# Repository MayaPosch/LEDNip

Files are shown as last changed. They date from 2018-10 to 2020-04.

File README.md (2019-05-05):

# LED'Nip #

 LED'Nip is a 5-channel Cortex-M4-based LED controller and general STM32 development board. It has the following features:

- STM32F427 microcontroller (Cortex-M4, 180 MHz).
- 100 MBit Ethernet (LAN8472A).
- CAN (RJ-45 jacks).
- Three 12V channels for RGB LED strips or similar.
- Two channels for ~25 Watt LED panels each (5.5/2.1 mm jack) with constant current regulator (1A LDD-1000H or equivalent per channel).
- 24 VDC board supply voltage.
- SPI, I2C, U(S)ART, I2S and JTAG broken out into JST PH headers.

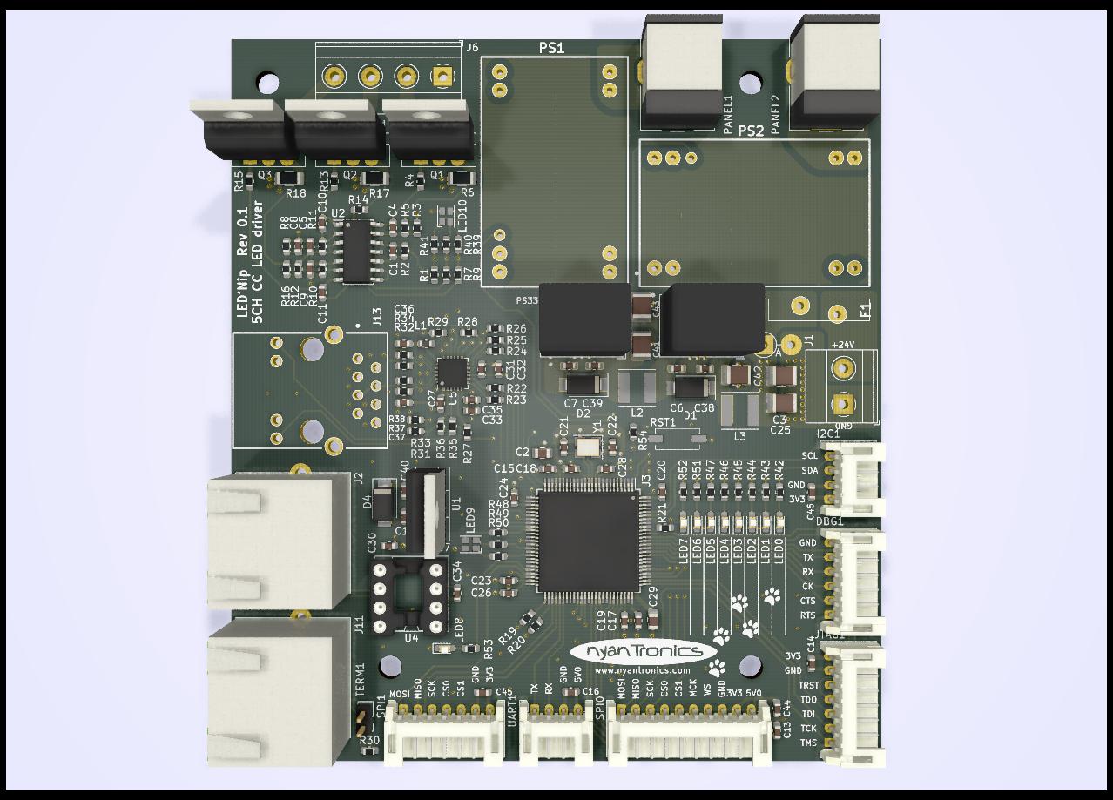
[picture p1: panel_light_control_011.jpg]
LED'Nip


## Status ##

The LED'Nip hardware has been mostly validated. Test firmware can be found in its folder, with the firmware and backend service that will allow for the board to be used with building lighting and similar still under development.

## Project page

A project & product page can be found at: [http://www.nyantronics.com/lednip.php](http://www.nyantronics.com/lednip.php "LED'Nip")

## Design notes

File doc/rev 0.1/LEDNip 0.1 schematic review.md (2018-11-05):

LEDNip 0.1 schematic review
===

OSHW Logo and license:
https://maciek134.github.io/oshw-logo-gen/

5 channel LED driver board with 10/100 ethernet and CAN BUS control. 

**Modules**
R78B12-2.0, R78B33-2.0 https://www.recom-power.com/pdf/Innoline/R-78Bxx-2.0.pdf
LDD-1000H https://www.mouser.com/ds/2/260/LDD-H-spec-766227.pdf
**ICs**
LM324 http://www.ti.com/lit/ds/snosc16d/snosc16d.pdf
STM32F207VGT6 https://www.st.com/resource/en/datasheet/stm32f207zg.pdf
MCP2562 http://hades.mech.northwestern.edu/images/5/5e/MCP2562.pdf
LAN8720A http://ww1.microchip.com/downloads/en/devicedoc/8720a.pdf
**Connectors**
HR911105A http://www.kosmodrom.com.ua/pdf/HR911105A.pdf
JST PH http://www.farnell.com/datasheets/1699381.pdf
CUI PJ-063AH https://www.cui.com/product/resource/pj-063ah.pdf
RJHSE-5380A1 https://www.mouser.de/datasheet/2/18/rjhsel38x02-1395709.pdf
Metz 31349102, 31349104 (Reichelt AKL349-xx) https://www.metz-connect.com/us/system/files/productfiles/Data_sheet_313491_RP015xxVBLC_OFF-023252M.pdf
Metz 31330102, 31330104 (Reichelt AKL330-xx) https://www.metz-connect.com/en/system/files/productfiles/Data_sheet_313301_PT115xxHBBN_OFF-022949N.pdf

Quick Review:
===

Schematic ERC
---
- nets with power inputs and no power outputs (even connectors) need a PWR_FLAG to represent power output, passives disconnect power nets (need another PWR_FLAG after filter inductor / resistor)
- no multiple bidirectional pins on one net (multiple output short prohibited)
- no bidirectional pin connected to a net with power output or PWR_FLAG (including ground)
- GND also needs one PWR_FLAG in the entire circuit
- more rules.. go figure

RMII interface signals
----
http://ebook.pldworld.com/_eBook/-Telecommunications,Networks-/TCPIP/RMII/rmii_rev12.pdf
https://en.wikipedia.org/wiki/Media-independent_interface
|Signal name |	Description |	Direction |
|---|---|---|---|
|REF_CLK| Continuous 50 MHz reference clock |	Reference clock may be an input on both devices from an external clock source, or may be driven from the MAC to the PHY |
|TXD0 	| Transmit data bit 0 (transmitted first) |	MAC to PHY |
|TXD1 	| Transmit data bit 1  |	MAC to PHY |
|TX_EN 	| When high, clock data on TXD0 and TXD1 to the transmitter |	MAC to PHY |
|RXD0 	| Receive data bit 0 (received first) |	PHY to MAC |
|RXD1 	| Receive data bit 1 |	PHY to MAC |
|CRS_DV | 	Carrier Sense (CRS) and RX_Data Valid (RX_DV) multiplexed on alternate clock cycles. In 10 Mbit/s mode, it alternates every 10 clock cycles. |	PHY to MAC |
|RX_ER 	| Receive error (optional on switches) |	PHY to MAC |
|MDIO 	| Management data |	Bidirectional |
|MDC 	| Management data clock. |	MAC to PHY |

Microcontroller
---------------
- BOOT strap config
-- https://www.st.com/resource/en/datasheet/stm32f207vg.pdf
-- https://www.st.com/resource/en/schematic_pack/nucleo_144pins_sch.zip
-- RM0033 reference manual: https://www.st.com/content/ccc/resource/technical/document/reference_manual/51/f7/f3/06/cd/b6/46/ec/CD00225773.pdf/files/CD00225773.pdf/jcr:content/translations/en.C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 boot0: Main Flash memory; BOOT0 is a dedicated pin while BOOT1 is ... GPIO; 47k unmotivated -> 1k 
- JTAG / SWD: JTRST->PB4 RM0033 ok (Table 15. Flexible SWJ-DP pin assignment) (Table 207. SWJ debug port pins)
-- JTAG and SWD pinouts verified 
- general pin mapping
-- CubeMX tool: https://www.st.com/en/development-tools/stm32cubemx.html#sw-tools-scroll

- CAN interface
-- "The two CANs are compliant with the 2.0A and B (active) specifications with a bitrate up to 1 Mbit/s. They can receive and transmit standard frames with 11-bit identifiers as well as extended frames with 29-bit identifiers. Each CAN has three transmit mailboxes, two receive FIFOS with 3 stages and 28 shared scalable filter banks"
-- CAN transceiver are equal? CubeMX says: "Master" for CAN1 (RM0033 p.793 "Controller area network (bxCAN)")
-- https://www.st.com/content/ccc/resource/training/technical/product_training/de/ee/37/c6/60/9c/45/a5/STM32L4_Peripheral_CAN.pdf/files/STM32L4_Peripheral_CAN.pdf/jcr:c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 
-- CAN2 RX and TX: changed SPI CS0, CS1 from PB6,PB7 to PB5+PB6 (also maps to the slave BxCAN pins for backup)

- clock generation and distribution
-- XTAL up to 26 MHz (also validated with CubeMX) (https://www.st.com/content/ccc/resource/technical/document/application_note/c6/eb/5e/11/e3/69/43/eb/CD00221665.pdf/files/CD00221665.pdf/jcr:content/translations/en.C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)
-- STM32 and LAN8720A timing requirements (jitter / tolerance), PLL behaviour: (RM0033: "The software has to set these bits correctly to ensure that the VCO input frequency ranges from 1 to 2 MHz. It is recommended to select a frequency of 2 MHz to limit PLL jitter") - 25 MHz could be routed directly from the oscillator (???) -- look at clock distribution: CubeMX: MCO1 supports HSE and PLL 
-- Table 34. Main PLL characteristics (continued): Cycle-to-cycle jitter 25ps RMS, +/-150ps(peak-peak), Period Jitter: 15ps, +/-200ps (peak-peak)
-- LAN8720A: CLKIN  Jitter 150 psec (peak-peak) max, 
- RMII timing analysis
-- datasheet "Table 64. Dynamics characteristics: Ethernet MAC signals for RMII" have to be met. All RMII traces are 50 mm max., accounting for < 300ps propagation delays. LAN8720A "Table 5.9 RMII Timing Values (REF_CLK Out Mode)" has the timing characteristics in REFCLKO mode.
-- at first glance, the mismatch between RXDn and REFCLK lines from PHY to MAC is < 10 mm, so the RX path signals can be considered to have perfect timing. For the TX path this already introduces a delay by how long it takes REFCLKO to propagate ~30 mm. The period of REFCLK is 20 ns and the MAC provides 9 ns minimum TXD and TXEN hold, followed by a transition zone of about 5 ns until the next transmit data is stable so there is a 20 ns- (9 + 5 ) ns = 6 ns minimum setup earlier on. When looked at from the MAC, the PHY clock is slightly ahead in time and along with it the PHY sampling edges. Consequently the PHY sampling is advanced by the PHY-> MAC REFCLK propagation delay plus the MAC->PHY TXDn propagation time. Due to the odd STM32 RMII pin mapping the TXDn traces are 60 mm long. Adding to that the REFCLK trace length we're talking about 100 mm or 0.5 ns propagation delay , leaving 5.5 ns timing buffer for delays and transitions. 
-- conclusion: RMII timing ought to be valid.

- RMII_RXER sowie can_stdby nicht in den alternate Functions, vermutlich da sie softwaremäßig umgesetzt sind
-- CAN_STDBY: GPIO (optional power-down for CAN level converter)
-- ds p.123 "Figure 50. Ethernet RMII timing diagram" RMII requires REF_CLK, RXD[1:0], TXD[1:0], CRS_DV, TX_EN. Table 64 below lists the timing constraints. 
-- RXER is not used on the MAC and connected to a PD on the STM32 nucleo board where the LAN8742A is used (see https://www.st.com/content/ccc/resource/technical/layouts_and_diagrams/schematic_pack/63/95/5c/0c/d6/af/4b/e2/nucleo_144pins_sch.zip/files/nucleo_144pins_sch.zip/jcr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 MB1137.pdf). On our board, it's connected to the microcontroller. As per LAN8720A, RXER acts as start-up PHYAD0 input with internal PD. No further action is required.

- Powersupply erwartet 100nF an jedem Supply-Pin, 7 Supply-Pins, aber nur 5 Caps: 2 vergessen?
-- pins 19, 21, 22 share C2+C15 (100n + 4.7µF). The same applies to C17 + C29

- 3 pF am Quarz ungewohnt wenig, aber Quarztyp im Schematic nicht zu lesen
-- ABM8W-25.0000MHZ-4-D1X-T3 https://www.mouser.de/datasheet/2/3/ABM8W-1107617.pdf und https://abracon.com/uploads/resources/qtzcry_glossary.pdf : C_L = C1*C2/(C1+C2)+C_stray
-- Oscillator design guide for STM8AF/AL/S and STM32 microcontrollers: https://www.st.com/content/ccc/resource/technical/document/application_note/c6/eb/5e/11/e3/69/43/eb/CD00221665.pdf/files/CD00221665.pdf/jcr:content/translations/en.C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 p.26 "Table 6. HSE oscillators embedded in STM32 microcontrollers": Step 1: Check the resonator compatibility with the selected STM32 (gain margin satisfied?), Step 2: Determine the capacitance value of the load capacitors C_L1 and C_L2
-- Datenblattwerte für Quarz C_L: 4pF, oscillator pins ~5pF (datasheet?), C_stray < 0.5 pF? -> ~4pF
-- ggf. sind Varianten mit höherer C_L wünschenswert, siehe AN2867 p.39 "[larger values, lower "pullability"]  can be used in noisy environments, but will impact the power consumption." -> ABM8-25.000MHZ-10-D1G-T (Mouser 815-8W25-4D1XT) -> 15pF load caps: C_L = 10pF
-- can always go crazier, see https://www.st.com/content/ccc/resource/technical/document/application_note/c6/eb/5e/11/e3/69/43/eb/CD00221665.pdf/files/CD00221665.pdf/jcr:content/translations/en.C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 p.33 and below

MCP2562
-------
- Pinout geprüft, keine Fehler
- Beschaltung wie im DS vorgeschlagen

LAN8720A
--------

| Pin | internal | external/override | Selected Function |
|---|---| ---|---|
| RXD0/MODE0 | PU | TRIS | MODE=111: all capable |
| RXD1/MODE1 | PU | TRIS | MODE=111: all capable |
| RXER/PHYAD0  | PD | TRIS | lo : addr = 000 | 
| CRS_DV/MODE2 | PU | TRIS | MODE=111: all capable |
| nINT | PU | TRIS | will be REFCLKO, don't care |
| RST | PU | PU | redundancy, don't care |
| LED1/REGOFF  | PD | LED to GND | lo: regulator active |
| LED2/nINTSEL | PU | PD | lo: REFCLK OUT selected |

validated.

- Pinout geprüft, keine Fehler
- PU/PD config: see above 
- Supply-Beschaltung wie im DS vorgeschlagen
- Warum sind RX-Pins mit 100 Ohm beschaltet, TX aber nicht?
-- series termination resistors are placed near the drivers. TX terminators are associated with the µC.
- Warum hat MDIO einen Pullup, die anderen Pins aber nicht?
-- MDC is driven by the MAC (master, push-pull), whereas MDIO is open drain and can be driven by PHYs and MAC. (Wiki. The MDIO requires a specific pull-up resistor of 1.5 kΩ to 10 kΩ, taking into account the total worst-case leakage current of 32 PHYs and one MAC.)
- An sonsten Beschaltung gemäß DS
-- \o/

HR911105A
---------
- Pinout geprüft, alles ok

LDD-1000H
---------
- Pinout geprüft, alles ok

R-78B3.3-1.0
------------
- Pinout ok
- Eingangsbeschaltung etwas random. Vermutlich einfach BOM kurz halten durch wiederholen von Captypen.
-- LDD-H modules don't necessarily need input bypass caps, leaving just R78B12-2.0. LC pi input filter inspired by the corresponding datasheet.
- D2 fragwürdig.
-- LDO downward compatibility

LED-Ausgangsstufen
------------------
- Pinout OP passt
- Sehe 2 Tiefpass-Filter, einen am Eingang für ca. ~500 Hz, einen aktiven am OP für ca. 50 kHz (BW limiting vs. 3 MHz GBP)

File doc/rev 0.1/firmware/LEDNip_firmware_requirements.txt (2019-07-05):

LEDNip firmware requirements

2019/07/02, Maya Posch
---

> Overview

This document describes the software requirements for the Nyantronics LEDNip board. The requisite backend service is covered in a different document.

---

> Inputs/Outputs

The firmware takes input from:

* Ethernet interface.
* CAN interface.

It has the following outputs:

* 2x PWM pins to control 2 CC LED drivers.
* 3x PWM pins to control 3 LED strip (colour) drivers.

---

> Basic functionality set

These are the minimal features which the firmware has to support for an MVP.

* Obtain an IP address from the DHCP server on the Ethernet network.
* Connect to an MQTT broker on this interface.
* Accept commands on the Ethernet interface via MQTT to:
	* change the outputs to a specific PWM value, ranging from 0 - 100%.
	* return the current values the PWM pins have been set to.

> Details:

Implemented as bare metal, using a basic processing loop.

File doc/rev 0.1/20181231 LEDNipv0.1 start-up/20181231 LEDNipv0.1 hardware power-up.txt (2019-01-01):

LEDNip-0.1 commissioning

Step 1:
3.3V and 0.02A limit to JTAG1 GND|3.3V pins: 3.3V 0.018A -> pass, no shorts
swap PSU: 3.3V (no precision current measurement)

Step 2:
12V rail: 2.4V backdriven through freewheeling diode (as expected)
slowly increase 12V rail to 5V with 0.02A limit, monitoring 3.3V rail
* current limit not exceeded
* 3.3V increases from 3.284V to 3.289V (in spec)
* 12V rail at 4.75V (current limit)
* 5V rail at 3.9V

increase current limit to 0.05A
* 12V rail at 5.0V
* monitor 5V rail, ramd up 12V rail to 12V
* 5V rail settles in at 5.078V (in spec)
* 3.3V rail at 3.308V (in spec)
* 24V rail at 11.48V

remove 3.3V injection
* rails still in spec
turn off power supplies

Step 3:
hook up adjustable power supply to 24V rail

* 24V rail to 3V: no current draw
* 24V rail to 12V: 2-3mA, 3.3V rail at 0.1V
* 24V rail to 14V: overcome UVLO, 16mA current draw
* 12V rail at 12.03V, 5V rail at 5.08V, 3.3V at 3.308V
* 24V rail to 24V: input current now 9mA
* 24V rail at 28V: 8mA

power-up test passed.

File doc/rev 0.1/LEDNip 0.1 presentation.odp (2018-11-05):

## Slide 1

LEDNip 0.1 - 5 channel LED driver board

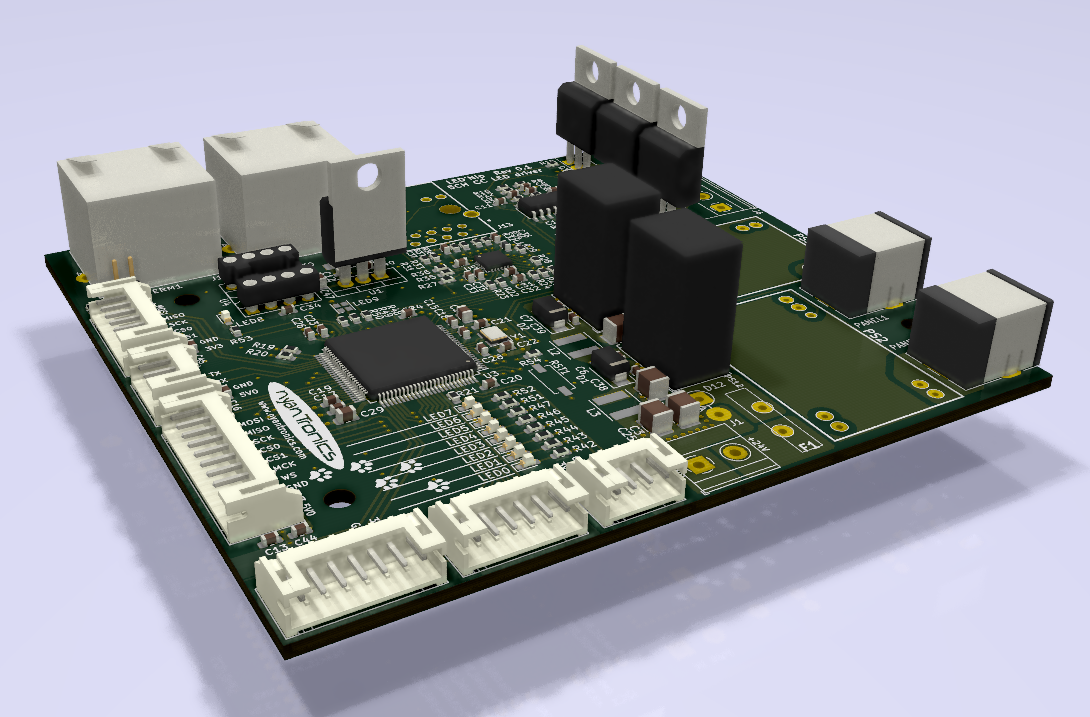
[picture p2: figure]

2018-11-05

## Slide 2

What?

- driver board for indoor LED lighting
- 2-channel 1A CC drivers for 8-24V LED chains (CUI barrel jacks for panels)
- 3-channel 1A CC drivers for RGB strips (linear / PWM)
- control via UART, CAN, Ethernet
- lots of peripherals for extensions and building automation
- compact 9x10cm 4-layer PCB for best performance

Open source hardware project

- multiple maintainers
- KiCAD project files
- open source firmware

BOM cost: 45-55€

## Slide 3

Features:

STM32F427 Cortex-M4 microcontroller

24V input for use with common power supplies (cost-effective fan-less MeanWell 100W)

2x 0..1000 mA CC LED driver

up to 97% efficiency

industry-proven potted module 2000Khrs min. MIL-HDBK-217F

PWM dimming (spec: < 1kHz, tested up to 7 kHz)

12V / 3.3V buck converter modules

multi-sourced potted modules from reputable manufacturers (RECOM, Gap-Tec)

on-board 3-channel current controller for RGB strips

10/100 Ethernet

CAN bus + daisychaining JR45 (CAT5)

JTAG/SWD

lots of interfaces for whatever comes our way

2x UART/USART w/ flow control

2x SPI (option for I2S)

I2C

secondary CAN

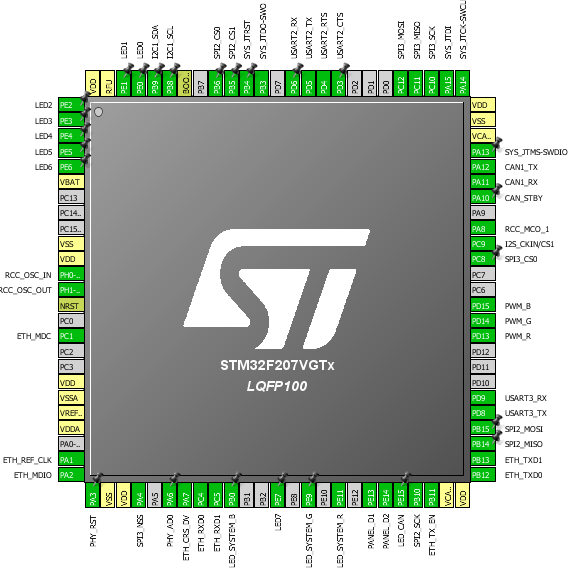
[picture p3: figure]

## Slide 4

multiple controller options:

can be adjusted to applications

less problems sourcing

Design tool CubeMX

Cortex-M3 / Cortex-M4 options

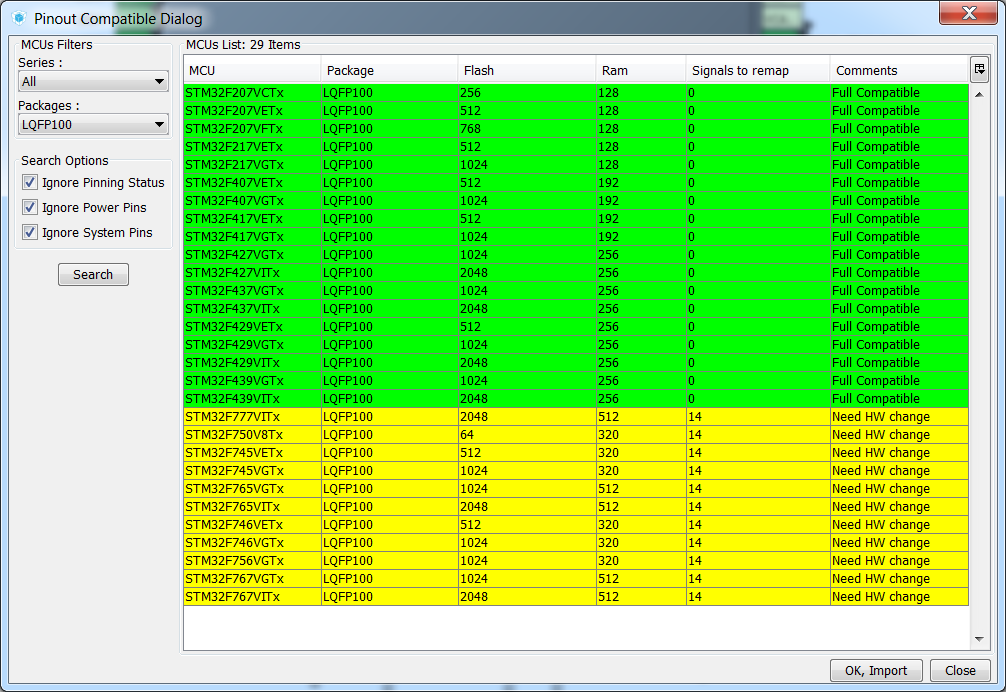
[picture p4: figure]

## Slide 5

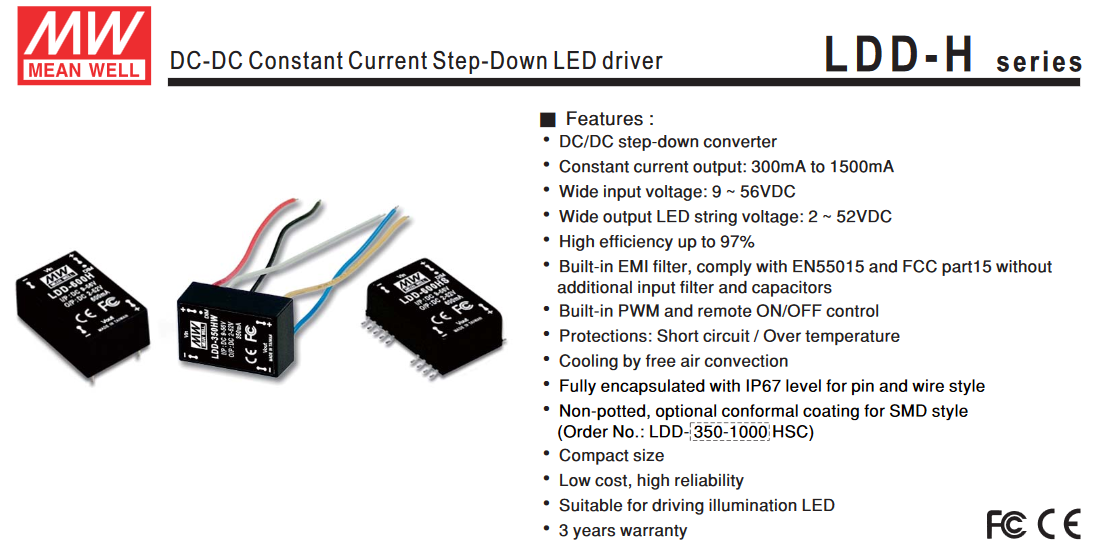
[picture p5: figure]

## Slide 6

Status?

- [done] Schematic design (~30h)
- [done] Schematic review (2 reviewers) (~5h)
- [done] Layout (~70h)
- [done] Layout validation (3 reviewers) (~5h)
- [done] parts availablilty check – mostly sourced from Mouser
- [ongoing] parts attributes in KiCAD and BOM export
- [done] experimental validation MeanWell LDD-1000H
- [done] experimental validation 1A linear CC sinks
- [pending] prototyping strategy (5+25 boards vs. 30+ boards at once, w/ stencil)
- [pending] parts sourcing (mission critical parts stocked)
- [ongoing] PCB assembly capabilities (professional P&P + reflow options, manual)
- [pending] prototype evaluation w/ PCBs
- [ongoing] firmware development

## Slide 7

KiCAD schematics and board files as OSHW

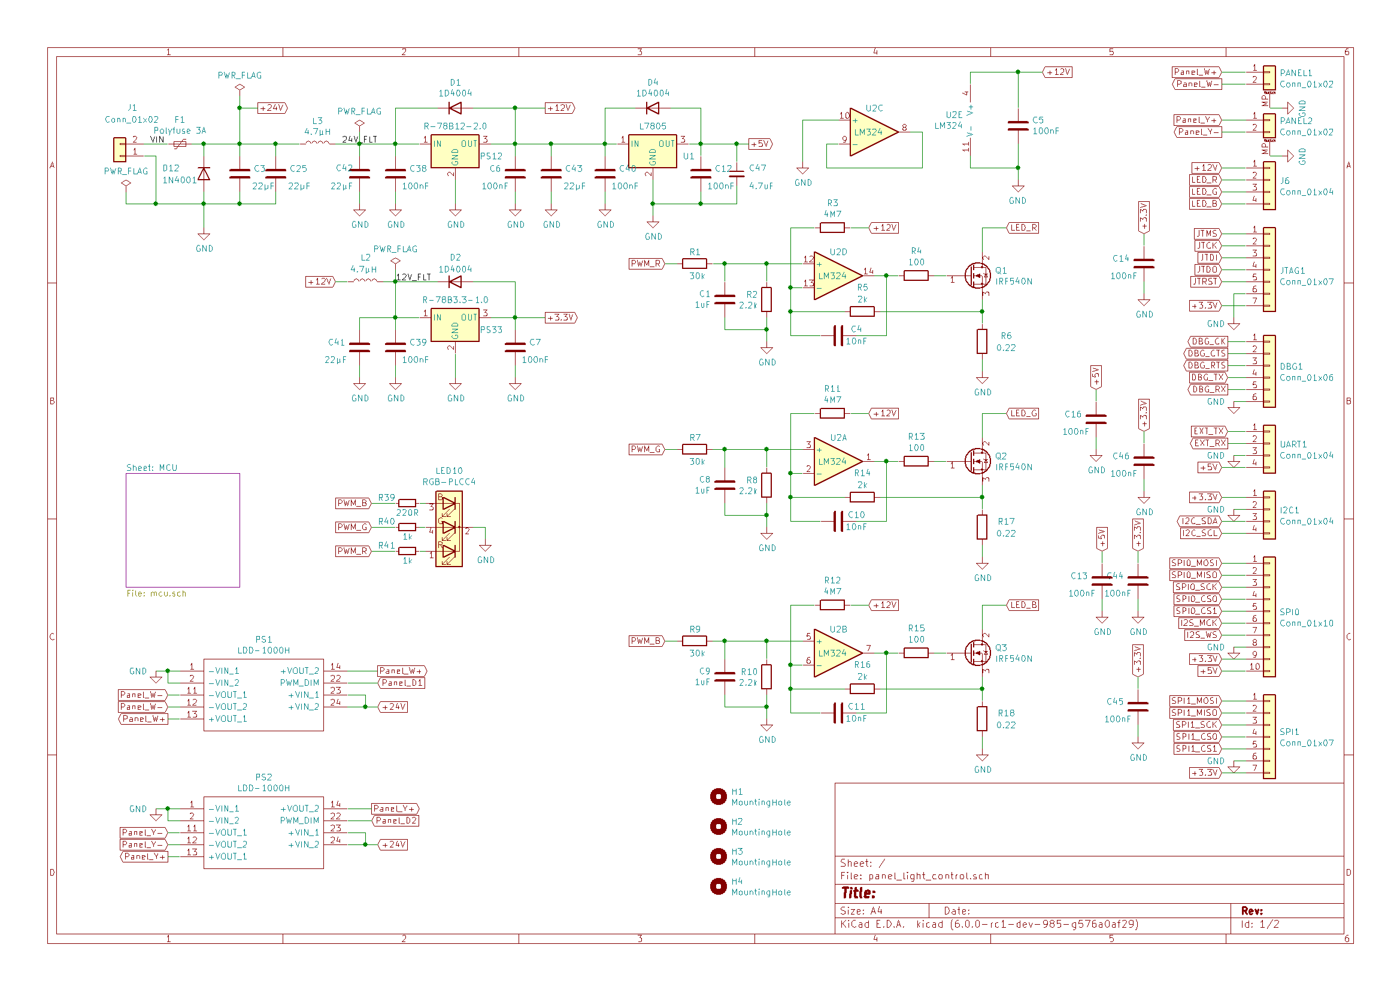
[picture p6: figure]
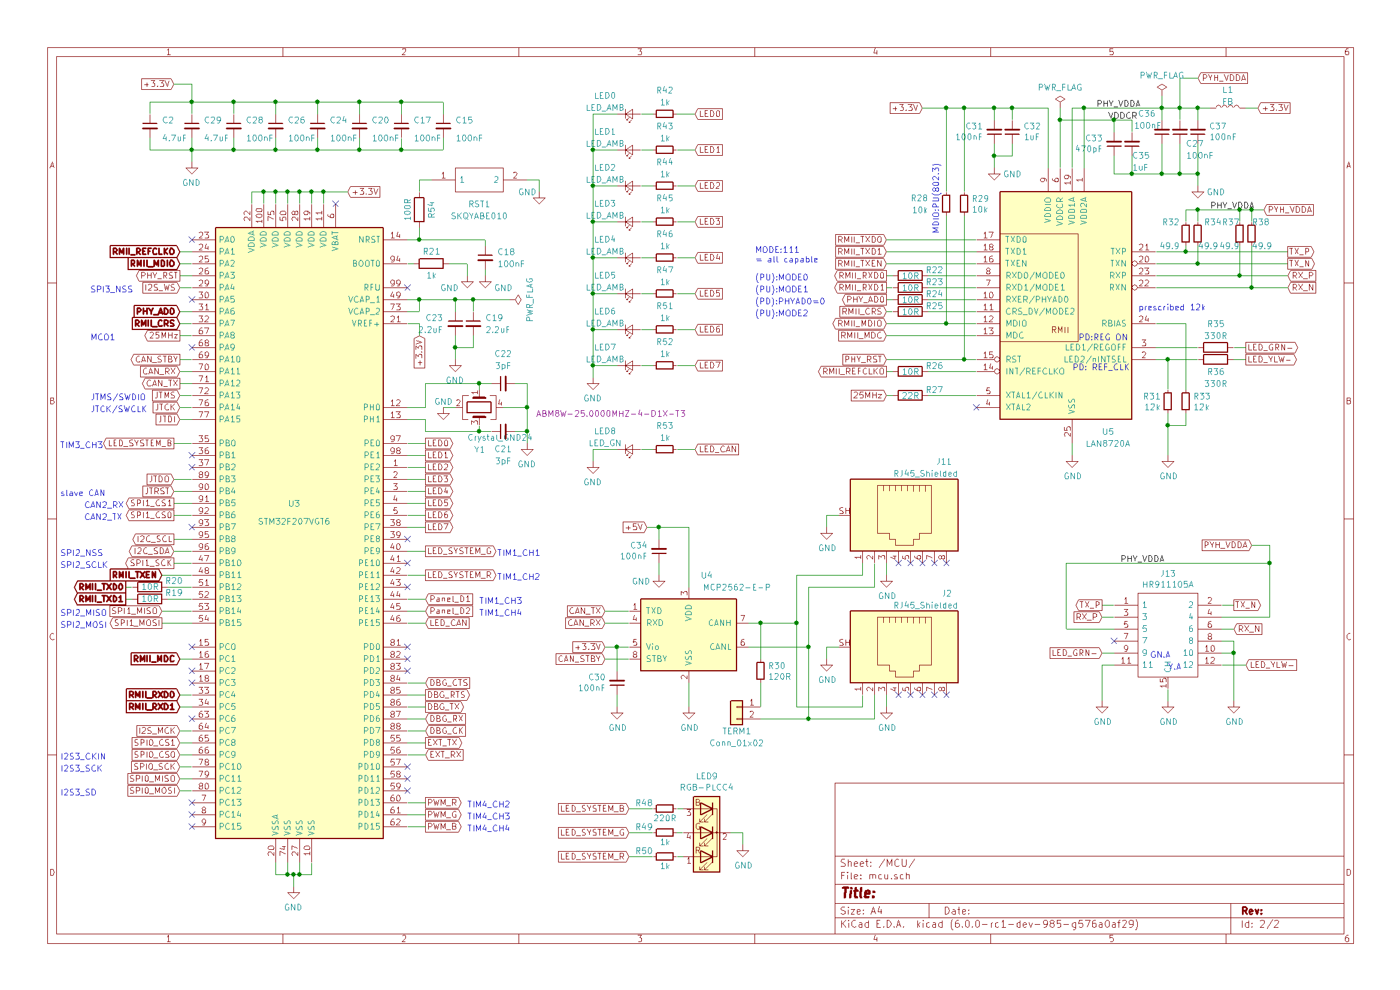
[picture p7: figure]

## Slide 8

KiCAD schematics and board files as OSHW

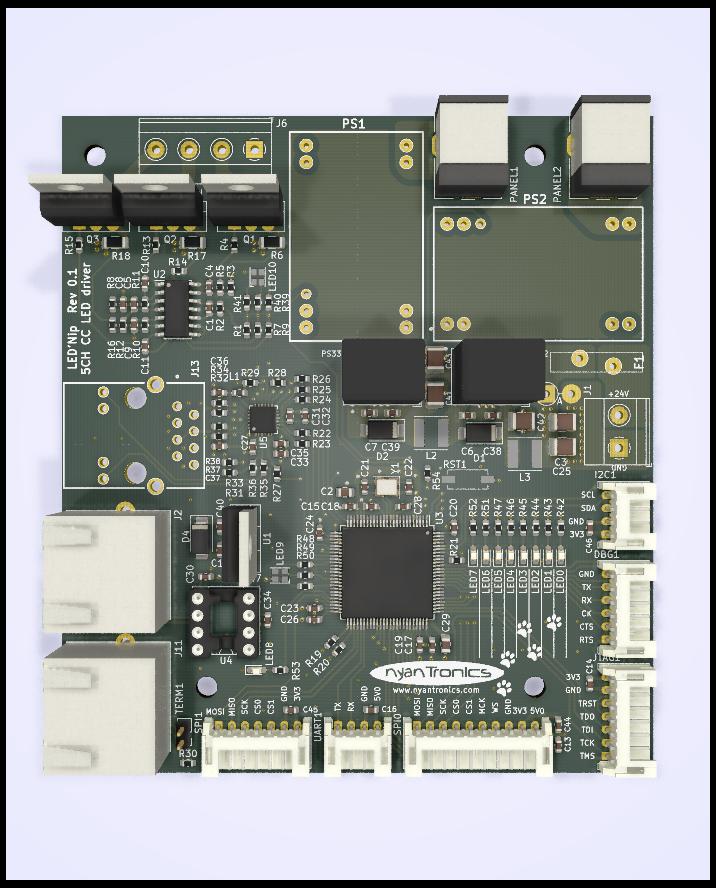
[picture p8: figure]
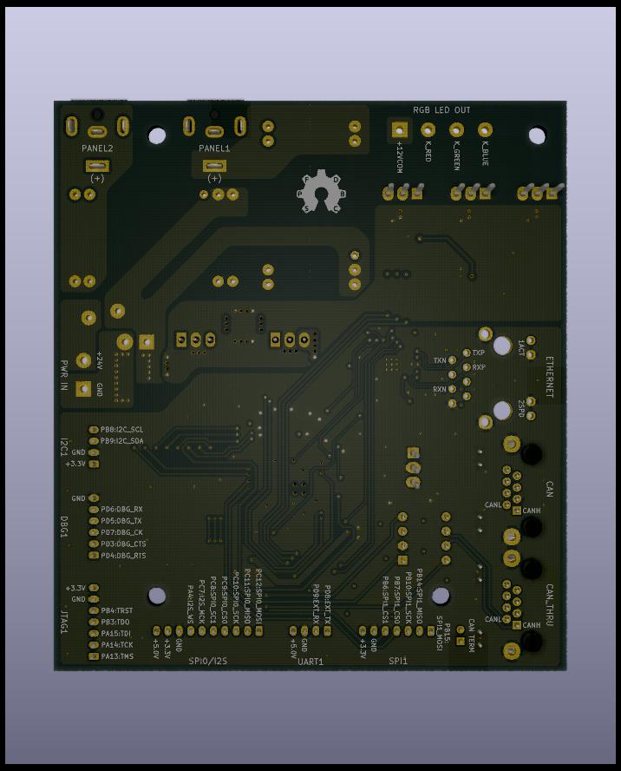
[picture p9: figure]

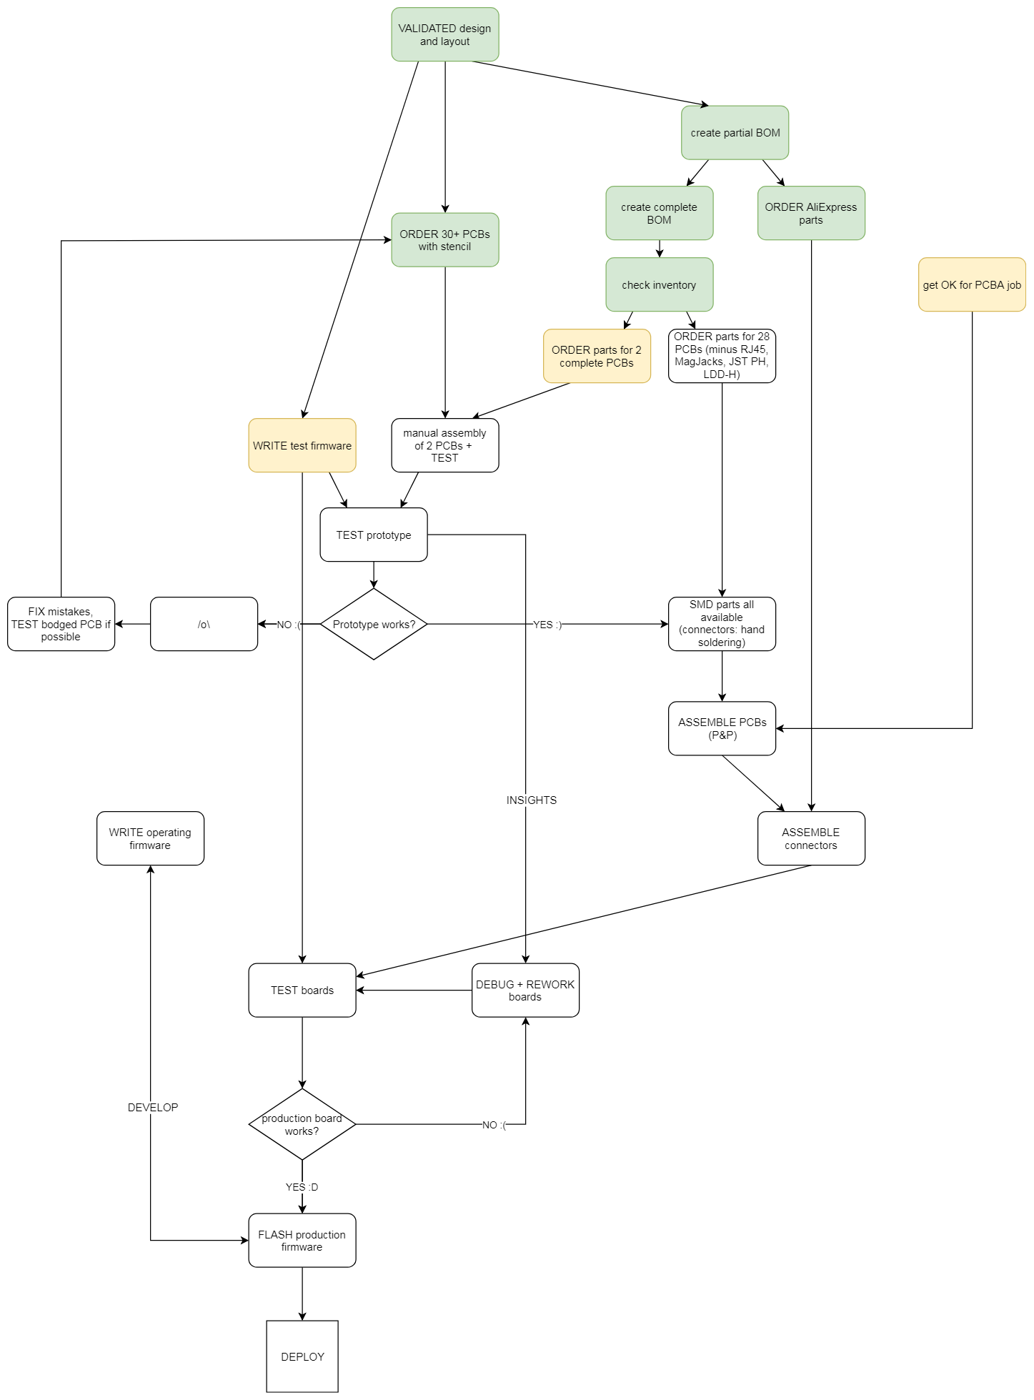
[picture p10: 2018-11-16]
doc/rev 0.1/LEDNip 0.1 hardware procedure.draw.io.png

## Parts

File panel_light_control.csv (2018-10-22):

Id | Designator | Package | Quantity | Designation | Supplier and ref
1 | D5 | LED_Cree-PLCC4_2x2mm_CW | 1 | LED_SYSTEM
2 | R5,R16,R14 | R_0603_1608Metric | 3 | 2k
3 | D11 | LED_0603_1608Metric_Castellated | 1 | LED_ColdWhite
4 | D7 | LED_0603_1608Metric_Castellated | 1 | LED_R
5 | D10 | LED_0603_1608Metric_Castellated | 1 | LED_WarmWhite
6 | D8 | LED_0603_1608Metric_Castellated | 1 | LED_G
7 | D6 | LED_0603_1608Metric_Castellated | 1 | LED_CAN
8 | D9 | LED_0603_1608Metric_Castellated | 1 | LED_B
9 | R47,R39,R40,R41,R42,R44,R43,R45,R46,R30 | R_0603_1608Metric | 10 | 120R
10 | R17,R18,R6 | R_1206_3216Metric | 3 | 0.22
11 | U2 | SOIC-14_3.9x8.7mm_P1.27mm | 1 | LM324
12 | C43,C42,C41,C25,C3 | C_1210_3225Metric | 5 | 22µF
13 | L3,L2 | L_Taiyo-Yuden_NR-50xx | 2 | 4.7µH
14 | C40,C39,C38,C27,C31,C5,C6,C7,C12,C15,C16,C17,C18,C20,C24,C26,C28,C30,C34,C36,C37 | C_0603_1608Metric | 21 | 100nF
15 | D3,D4,D2,D1 | D_SMA | 4 | 1D4004
16 | SPI0 | JST_PH_S11B-PH-K_1x11_P2.00mm_Horizontal | 1 | Conn_01x10
17 | R15,R4,R13 | R_0603_1608Metric | 3 | 100
18 | R12,R3,R11 | R_0603_1608Metric | 3 | 1M
19 | R10,R2,R8 | R_0603_1608Metric | 3 | 2.2k
20 | R9,R1,R7 | R_0603_1608Metric | 3 | 30k
21 | Q1,G3,Q2 | TO-220-3_Vertical | 3 | IRF540N
22 | J2,J11 | RJ45_Amphenol_RJHSE5380 | 2 | RJ45_Shielded
23 | F1 | Fuse_2512_6332Metric | 1 | Polyfuse_Small
24 | C21,C22 | C_0603_1608Metric | 2 | 3pF
25 | C11,C4,C10 | C_0603_1608Metric | 3 | 10nF
26 | C9,C1,C32,C8,C35 | C_0603_1608Metric | 5 | 1uF
27 | R25,R26,R19,R20,R22,R23,R24 | R_0603_1608Metric | 7 | 10R
28 | J6 | TerminalBlock_Phoenix_MKDS-1,5-4_1x04_P5.00mm_Horizontal | 1 | Conn_01x04
29 | H4,H2,H1,H3 | MountingHole_3.2mm_M3_DIN965 | 4 | MountingHole
30 | J13 | HR911105A_1 | 1 | HR911105A
31 | PS3,PS4 | LDD-700H | 2 | LDD-1000H
32 | C19,C23 | C_0603_1608Metric | 2 | 2.2uF
33 | C29 | C_0603_1608Metric | 1 | 4.7uF
34 | C33 | C_0603_1608Metric | 1 | 470pF
35 | I2C1,UART1 | JST_PH_S4B-PH-K_1x04_P2.00mm_Horizontal | 2 | Conn_01x04
36 | DBG1,JTAG1 | JST_PH_S6B-PH-K_1x06_P2.00mm_Horizontal | 2 | Conn_01x06
37 | SPI1 | JST_PH_S7B-PH-K_1x07_P2.00mm_Horizontal | 1 | Conn_01x07
38 | L1 | L_0603_1608Metric | 1 | FB
39 | PS2 | Converter_DCDC_RECOM_R-78E-0.5_THT | 1 | R-78B3.3-1.0
40 | R21 | R_0603_1608Metric | 1 | 47k
41 | R27 | R_0603_1608Metric | 1 | 22R
42 | R28,R29 | R_0603_1608Metric | 2 | 10k
43 | R31,R33 | R_0603_1608Metric | 2 | 12k
44 | R32,R34,R37,R38 | R_0603_1608Metric | 4 | 49.9
45 | R35,R36 | R_0603_1608Metric | 2 | 330R
46 | U1 | TO-220-3_Vertical | 1 | L7805
47 | U3 | LQFP-100_14x14mm_P0.5mm | 1 | STM32F207VGT6
48 | U4 | DIP-8_W7.62mm_Socket | 1 | MCP2562-E-P
49 | U5 | QFN-24-1EP_4x4mm_P0.5mm_EP2.6x2.6mm | 1 | LAN8720A
50 | Y1 | Crystal_SMD_Abracon_ABM8G-4Pin_3.2x2.5mm | 1 | Crystal_GND24
51 | J1 | TerminalBlock_Phoenix_MKDS-1,5-2_1x02_P5.00mm_Horizontal | 1 | Conn_01x02
52 | PS1 | Converter_DCDC_RECOM_R-78B-2.0_THT | 1 | R-78B12-2.0
53 | PANEL1,PANEL2 | BarrelJack_CUI_PJ-063AH_Horizontal | 2 | Conn_01x02

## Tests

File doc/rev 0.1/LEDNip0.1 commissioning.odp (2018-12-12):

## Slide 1

LEDNip 0.1 commissioning

20181209

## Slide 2

visual inspection

- prototype PCB, initial attempt to use lead-free solder paste (partial success)
- SMD assembly finalized by hand soldering
- additional flux paste used
- manual cleaning with CRC LR
- initial inspection of solder joints OK
- additional JST PH connectors soldered
- 3.3V rail driven by lab power supply: solid short
  voltages across bypass caps: lowest on C24

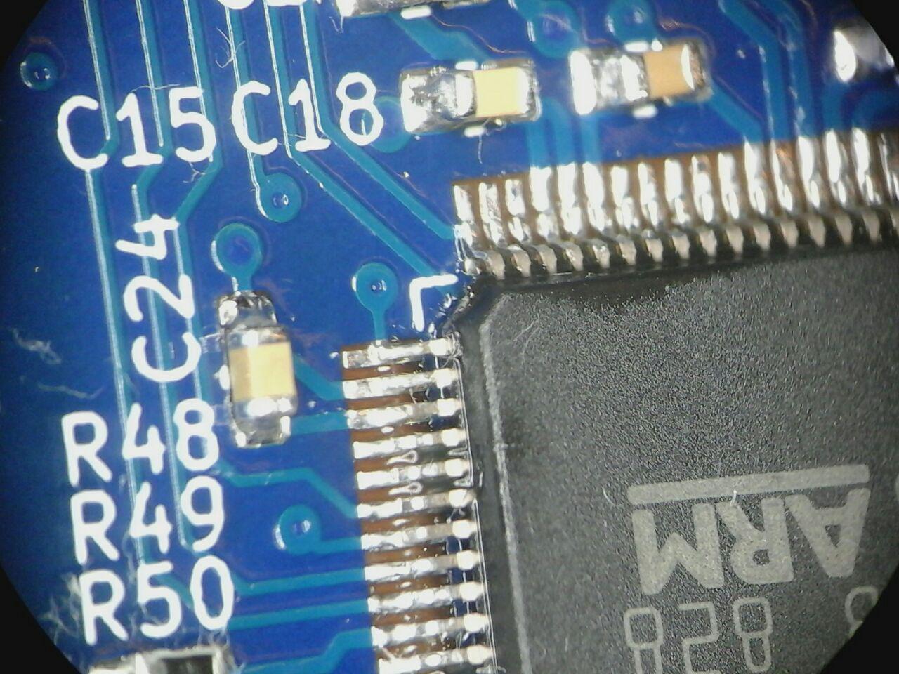
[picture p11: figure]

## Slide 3

visual inspection

- short circuit identified as a 30-50 µm dia. metallic particle stuck to the heel fillets of the 0.5mm pitch TQFP (solder tip / brass sponge contamination?)

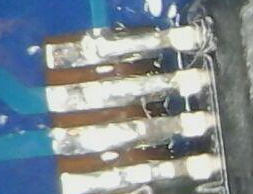
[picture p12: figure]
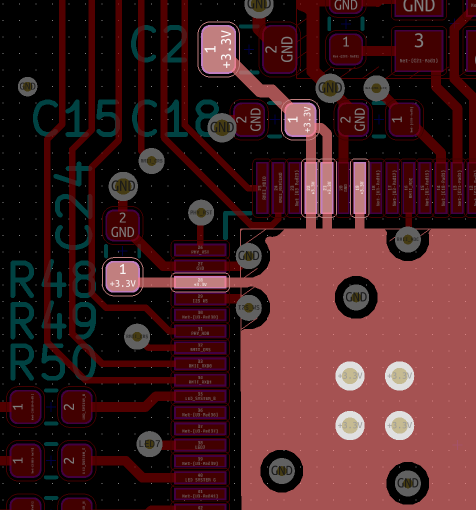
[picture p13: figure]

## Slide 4

visual inspection

- short circuit removed with scalpel
- board powers up, 17 mA @ 3.3 V
- reference board w/o µC: 13 mA seems plausible
- board deemed acceptable for subsequent THT assembly
  short circuit resolved with scalpel (see picture to the right)

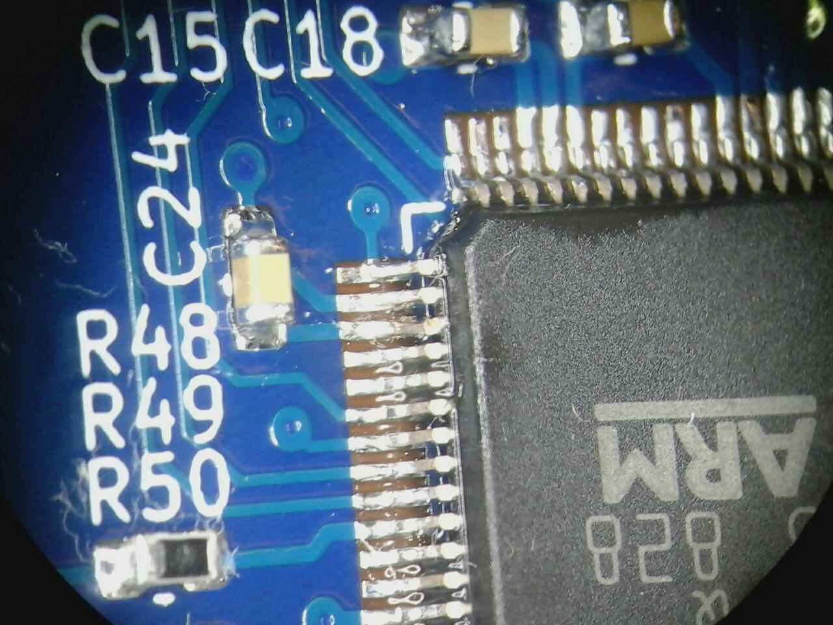
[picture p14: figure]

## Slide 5

THT assembly

- board fully populated (see right)
- no footprint mismatches
- all parts have proper footprints except
  for the 2.0 mm jumper (CAN term)
  which was intended to be 2.54 mm.
- Resolve by buying 2.0mm pin headers
  and jumpers (no big deal)
- no problems running the PH connectors at 1A for some time
- Lessons learnt: soldering iron cannot
  transfer enough heat to vias w/o
  thermals and too small restring.
  Further complicated by power planes.
  Next time: use offset pads,
  larger restring, thermals
  for all signals and generally @ < 1.0A

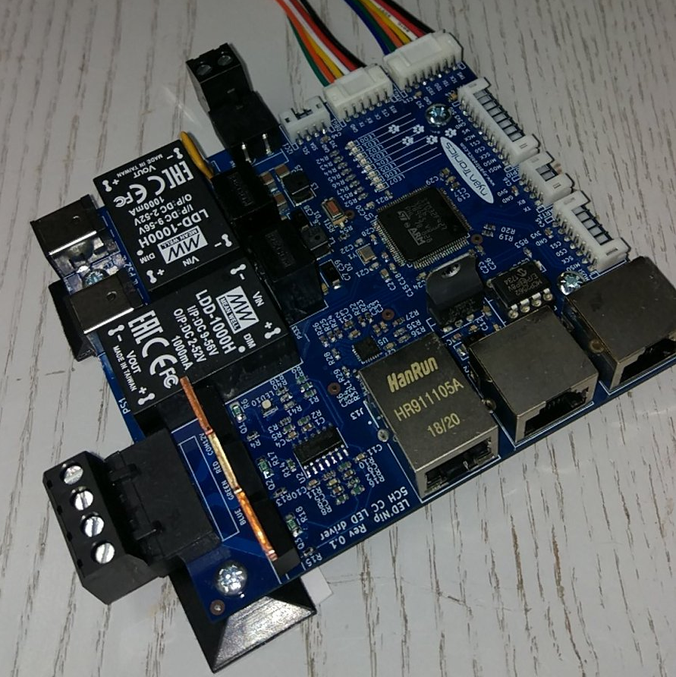
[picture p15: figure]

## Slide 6

power-up

verify MeanWell LDD-1000H pull-up voltage

reverse polarity protection diodes across DCDC modules and 5V regulator:
* backfeeds 12V rail with ~2.6V

* drives 5V LDO (no output produced, see next slide)

* backfeeds 24V rail with ~1.9V

3.3V rail: tested

5V rail ? todo: tie 5V and 12V together, ramp up to 5.0V, check for excessive current > 50 mA

12V rail ? todo: ramp-up with current limit, check 3.3V and 5V in spec

24V rail ? todo: ramp up with current limit, check 12V in spec

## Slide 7

power-up

simulated 1R load:

excessive current draw starts

at 4.0V input and quickly rises

above 100mA.

Pass/fail?

Try to get to 5V with 50mA limit.

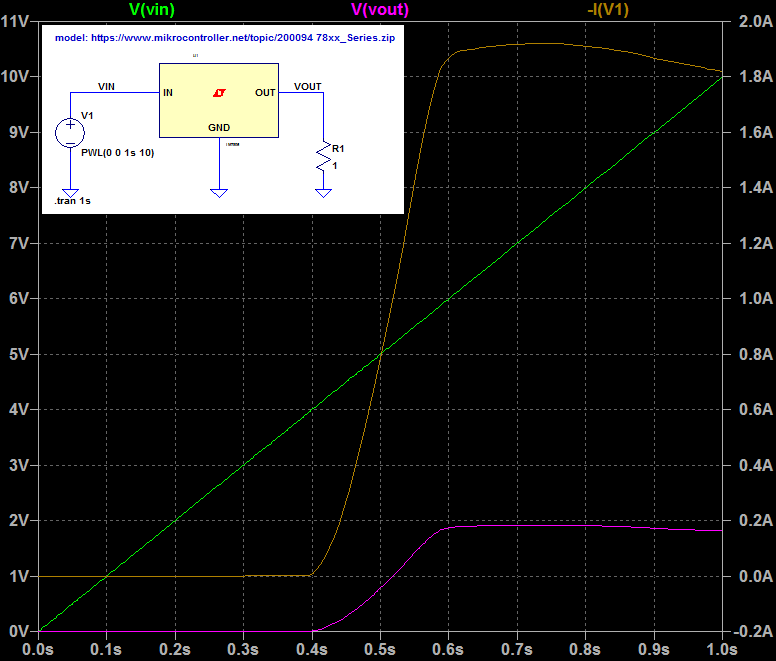
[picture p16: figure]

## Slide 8

power-up

7805 ramp-up behaviour does not

seem to be spec’ed in datasheets.

behaviour when tested

via 12V rail ramp only:

2.6V input: no output

(3.3V backfeed voltage)

3.5-4V input: output should ramp.

if 5V rail does not rise /

excessive current draw

> 20mA: investigate 5V

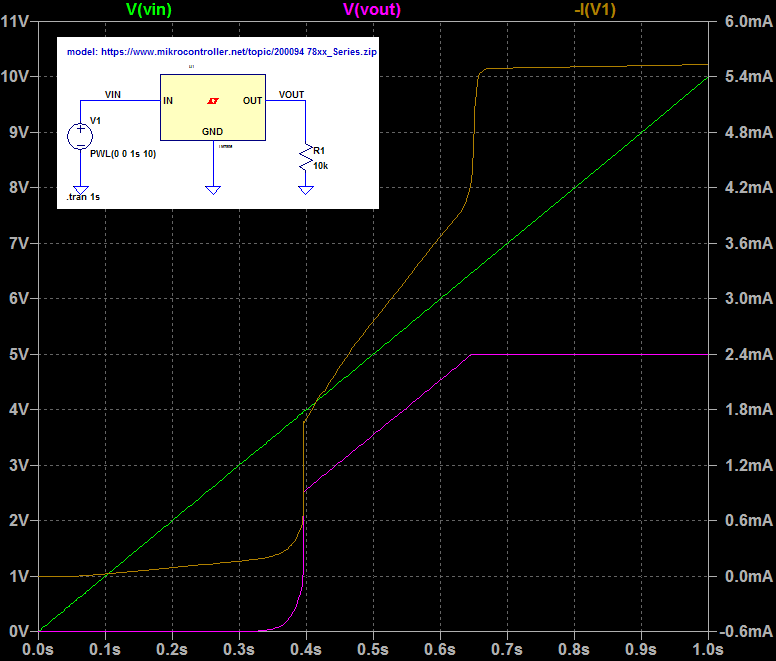
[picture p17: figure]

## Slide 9

tbd

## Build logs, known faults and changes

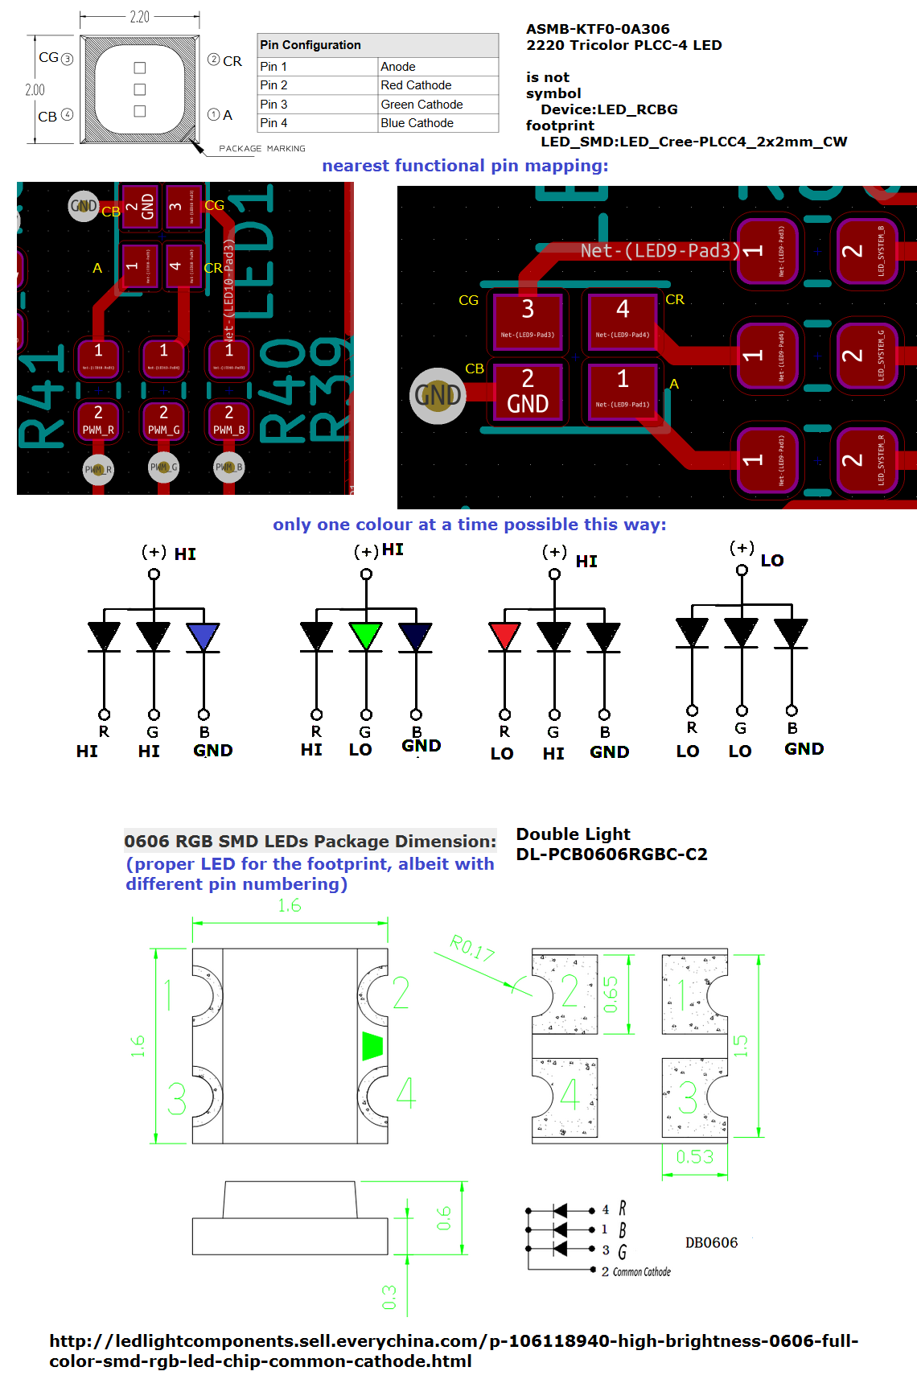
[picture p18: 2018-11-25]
doc/rev 0.1/LEDNip0.1-RGB-fix.png

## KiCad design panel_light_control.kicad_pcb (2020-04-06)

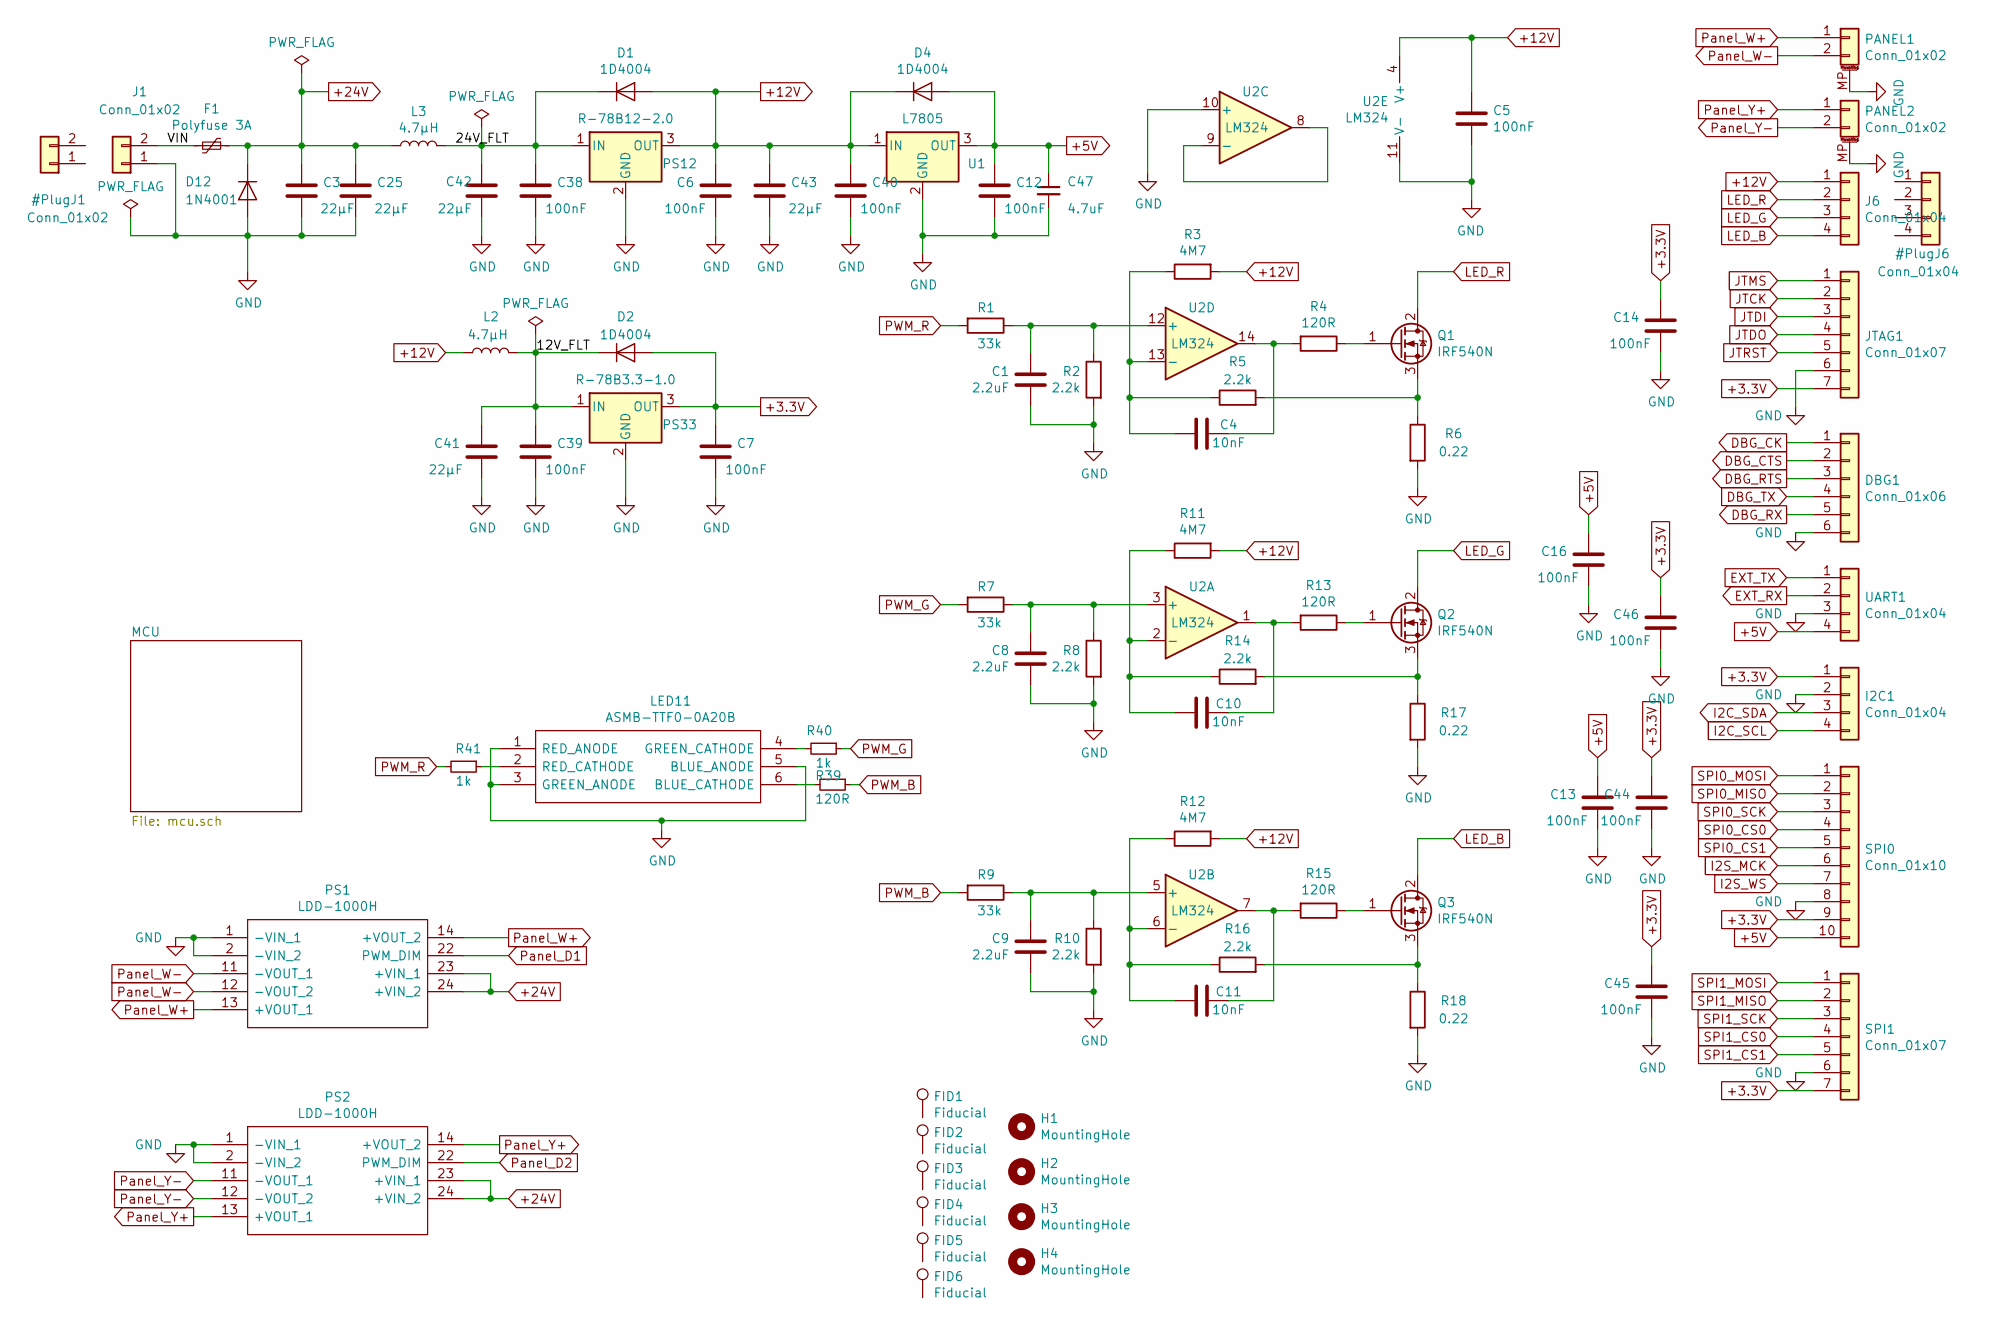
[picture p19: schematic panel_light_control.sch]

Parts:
C1, C8, C9: 2.2uF; C_0603_1608Metric; MPN C0603C225K9RACTU; Mouser 80-C0603C225K9R
C3, C25, C41, C42, C43: 22µF; C_1210_3225Metric; MPN GMK325BJ226MM-P; Mouser 963-GMK325BJ226MM-P
C4, C10, C11: 10nF; C_0603_1608Metric; MPN C0603C103K1REAUTO; Mouser 80-C0603C103K1REAUTO
C5, C6, C7, C12, C13, C14, C16, C38, C39, C40, C44, C45, C46: 100nF; C_0603_1608Metric; MPN C0603C104K5RECAUTO; Mouser 80-C0603C104K5REAUTO
C47: 4.7uF; C_0805_2012Metric; MPN GRM21BR71A475KE51L; Mouser 81-GRM21BR71A475KE1L
D1, D2, D4: 1D4004; D_SMA; MPN CGRA4004-G; Mouser 750-CGRA4004-G
D12: 1N4001; D_DO-41_SOD81_P3.81mm_Vertical_AnodeUp; MPN 1N4004-T; Mouser 621-1N4004
DBG1: Conn_01x06; JST_PH_S6B-PH-K_1x06_P2.00mm_Horizontal; MPN S6B-PH-K-S(LF)(SN)‎; DigiKey 455-1723-ND‎
F1: Polyfuse 3A; 30R400UF; MPN 30R300UU; Mouser 576-30R300UU
FID1, FID2, FID3, FID4, FID5, FID6: Fiducial; Fiducial_1mm_Dia_2.54mm_Outer_CopperTop
H1, H2, H3, H4: MountingHole; MountingHole_3.2mm_M3_DIN965
I2C1: Conn_01x04; JST_PH_S4B-PH-K_1x04_P2.00mm_Horizontal; MPN S4B-PH-K-S(LF)(SN)‎; DigiKey 455-1721-ND‎
J1: Conn_01x02; TerminalBlock_Phoenix_MKDS-1,5-2_1x02_P5.00mm_Horizontal; MPN 31320102; Mouser 571-796644-2
J6: Conn_01x04; TerminalBlock_Phoenix_MKDS-1,5-4_1x04_P5.00mm_Horizontal; MPN 31320104
JTAG1: Conn_01x07; JST_PH_S7B-PH-K_1x07_P2.00mm_Horizontal; MPN S7B-PH-K-S(LF)(SN)‎; DigiKey 455-1724-ND‎
L2, L3: 4.7µH; L_Taiyo-Yuden_NR-50xx; MPN VLS5045EX-4R7M-CA; Mouser 810-VLS5045EX4R7MCA
LED11: ASMB-TTF0-0A20B; ASMBTTF00A20B; Manufacturer_Part_Number ASMB-TTF0-0A20B; Mouser Part Number 630-ASMB-TTF0-0A20B
PANEL1, PANEL2: Conn_01x02; BarrelJack_CUI_PJ-063AH_Horizontal; MPN PJ-063AH; Mouser 490-PJ-063AH
PS1, PS2: LDD-1000H; LDD-700H; Manufacturer_Part_Number LDD-1000H; Mouser 709-LDD-1000H
PS12: R-78B12-2.0; Converter_DCDC_RECOM_R-78B-2.0_THT; Manufacturer_Part_Number R-78B12-2.0; Mouser 919-R-78B12-2.0
PS33: R-78B3.3-1.0; Converter_DCDC_RECOM_R-78B-2.0_THT; MPN R-78B3.3-1.0; Mouser 919-R-78B3.3-1.0
Q1, Q2, Q3: IRF540N; TO-220-3_Vertical; MPN IRF540NPBF; Mouser 942-IRF540NPBF
R1, R7, R9: 33k; R_0603_1608Metric; MPN RC0603FR-0733KL; Mouser 603-RC0603FR-0733KL
R2, R5, R8, R10, R14, R16: 2.2k; R_0603_1608Metric; MPN RC0603FR-072K2L; Mouser 603-RC0603FR-072K2L
R3, R11, R12: 4M7; R_0603_1608Metric; MPN RC0603FR-074M7L; Mouser 603-RC0603FR-074M7L
R4, R13, R15, R39: 120R; R_0603_1608Metric; MPN RC0603FR-07120RL; Mouser 603-RC0603FR-07120RL
R6, R17, R18: 0.22; R_1206_3216Metric; MPN KRL1632E-M-R220-F-T5; Mouser 754-KRL1632EMR220FT5
R40, R41: 1k; R_0603_1608Metric; MPN RC0603FR-071KL; Mouser 603-RC0603FR-071KL
SPI0: Conn_01x10; JST_PH_S10B-PH-K_1x10_P2.00mm_Horizontal; MPN S10B-PH-K-S(LF)(SN)‎; DigiKey 455-1727-ND‎
SPI1: Conn_01x07; JST_PH_S7B-PH-K_1x07_P2.00mm_Horizontal; MPN S7B-PH-K-S(LF)(SN); DigiKey 455-1724-ND‎
U1: L7805; TO-220-3_Vertical; MPN L7805CV; Mouser 511-L7805CV
U2: LM324; SOIC-14_3.9x8.7mm_P1.27mm; MPN LM324ADR; Mouser 595-LM324ADR
UART1: Conn_01x04; JST_PH_S4B-PH-K_1x04_P2.00mm_Horizontal; MPN S4B-PH-K-S(LF)(SN)‎; DigiKey 455-1721-ND‎

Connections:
+3.3V: C7.1, C14.1, C44.1, C45.1, C46.1, D2.2 (A), I2C1.1, JTAG1.7, PS33.3 (OUT), SPI0.9, SPI1.7; also elsewhere on the board
+5V: C12.1, C13.1, C16.1, C47.1, D4.2 (A), SPI0.10, U1.3 (OUT), UART1.4; also elsewhere on the board
+12V: C5.2, C6.1, C40.1, C43.1, D1.2 (A), D4.1 (K), J6.1, L2.1, PS12.3 (OUT), R3.2, R11.2, R12.2, U1.1 (IN), U2.4 (V+)
+24V: C3.1, C25.1, D12.1 (K), F1.1, L3.1, PS1.23 (+VIN_1), PS1.24 (+VIN_2), PS2.23 (+VIN_1), PS2.24 (+VIN_2)
/12V_FLT: C39.1, C41.1, D2.1 (K), L2.2, PS33.1 (IN)
/24V_FLT: C38.1, C42.1, D1.1 (K), L3.2, PS12.1 (IN)
/VIN: F1.2, J1.2
DBG_CK: DBG1.1; also elsewhere on the board
DBG_CTS: DBG1.2; also elsewhere on the board
DBG_RTS: DBG1.3; also elsewhere on the board
DBG_RX: DBG1.5; also elsewhere on the board
DBG_TX: DBG1.4; also elsewhere on the board
EXT_RX: UART1.2; also elsewhere on the board
EXT_TX: UART1.1; also elsewhere on the board
GND: C1.1, C3.2, C5.1, C6.2, C7.2, C8.1, C9.1, C12.2, C13.2, C14.2, C16.2, C25.2, C38.2, C39.2, C40.2, C41.2, C42.2, C43.2, C44.2, C45.2, C46.2, C47.2, D12.2 (A), DBG1.6, I2C1.2, J1.1, JTAG1.6, LED11.1 (RED_ANODE), LED11.3 (GREEN_ANODE), LED11.5 (BLUE_ANODE), PANEL1.MP (MountPin), PANEL2.MP (MountPin), PS1.1 (-VIN_1), PS1.2 (-VIN_2), PS2.1 (-VIN_1), PS2.2 (-VIN_2), PS12.2 (GND), PS33.2 (GND), R2.2, R6.2, R8.2, R10.2, R17.2, R18.2, SPI0.8, SPI1.6, U1.2 (GND), U2.10 (+), U2.11 (V-), UART1.3; also elsewhere on the board
I2C_SCL: I2C1.4; also elsewhere on the board
I2C_SDA: I2C1.3; also elsewhere on the board
I2S_MCK: SPI0.6; also elsewhere on the board
I2S_WS: SPI0.7; also elsewhere on the board
JTCK: JTAG1.2; also elsewhere on the board
JTDI: JTAG1.3; also elsewhere on the board
JTDO: JTAG1.4; also elsewhere on the board
JTMS: JTAG1.1; also elsewhere on the board
JTRST: JTAG1.5; also elsewhere on the board
LED_B: J6.4, Q3.2 (D)
LED_G: J6.3, Q2.2 (D)
LED_R: J6.2, Q1.2 (D)
unnamed: C1.2, R1.1, R2.1, U2.12 (+)
unnamed: C4.1, R4.2, U2.14
unnamed: C4.2, R3.1, R5.1, U2.13 (-)
unnamed: C8.2, R7.1, R8.1, U2.3 (+)
unnamed: C9.2, R9.1, R10.1, U2.5 (+)
unnamed: C10.1, R13.2, U2.1
unnamed: C10.2, R11.1, R14.1, U2.2 (-)
unnamed: C11.1, R15.2, U2.7
unnamed: C11.2, R12.1, R16.1, U2.6 (-)
unnamed: LED11.2 (RED_CATHODE), R41.1
unnamed: LED11.4 (GREEN_CATHODE), R40.2
unnamed: LED11.6 (BLUE_CATHODE), R39.2
unnamed: Q1.1 (G), R4.1
unnamed: Q1.3 (S), R5.2, R6.1
unnamed: Q2.1 (G), R13.1
unnamed: Q2.3 (S), R14.2, R17.1
unnamed: Q3.1 (G), R15.1
unnamed: Q3.3 (S), R16.2, R18.1
unnamed: U2.8, U2.9 (-)
PWM_B: R9.2, R39.1; also elsewhere on the board
PWM_G: R7.2, R40.1; also elsewhere on the board
PWM_R: R1.2, R41.2; also elsewhere on the board
Panel_D1: PS1.22 (PWM_DIM); also elsewhere on the board
Panel_D2: PS2.22 (PWM_DIM); also elsewhere on the board
Panel_W+: PANEL1.1, PS1.13 (+VOUT_1), PS1.14 (+VOUT_2)
Panel_W-: PANEL1.2, PS1.11 (-VOUT_1), PS1.12 (-VOUT_2)
Panel_Y+: PANEL2.1, PS2.13 (+VOUT_1), PS2.14 (+VOUT_2)
Panel_Y-: PANEL2.2, PS2.11 (-VOUT_1), PS2.12 (-VOUT_2)
SPI0_CS0: SPI0.4; also elsewhere on the board
SPI0_CS1: SPI0.5; also elsewhere on the board
SPI0_MISO: SPI0.2; also elsewhere on the board
SPI0_MOSI: SPI0.1; also elsewhere on the board
SPI0_SCK: SPI0.3; also elsewhere on the board
SPI1_CS0: SPI1.4; also elsewhere on the board
SPI1_CS1: SPI1.5; also elsewhere on the board
SPI1_MISO: SPI1.2; also elsewhere on the board
SPI1_MOSI: SPI1.1; also elsewhere on the board
SPI1_SCK: SPI1.3; also elsewhere on the board

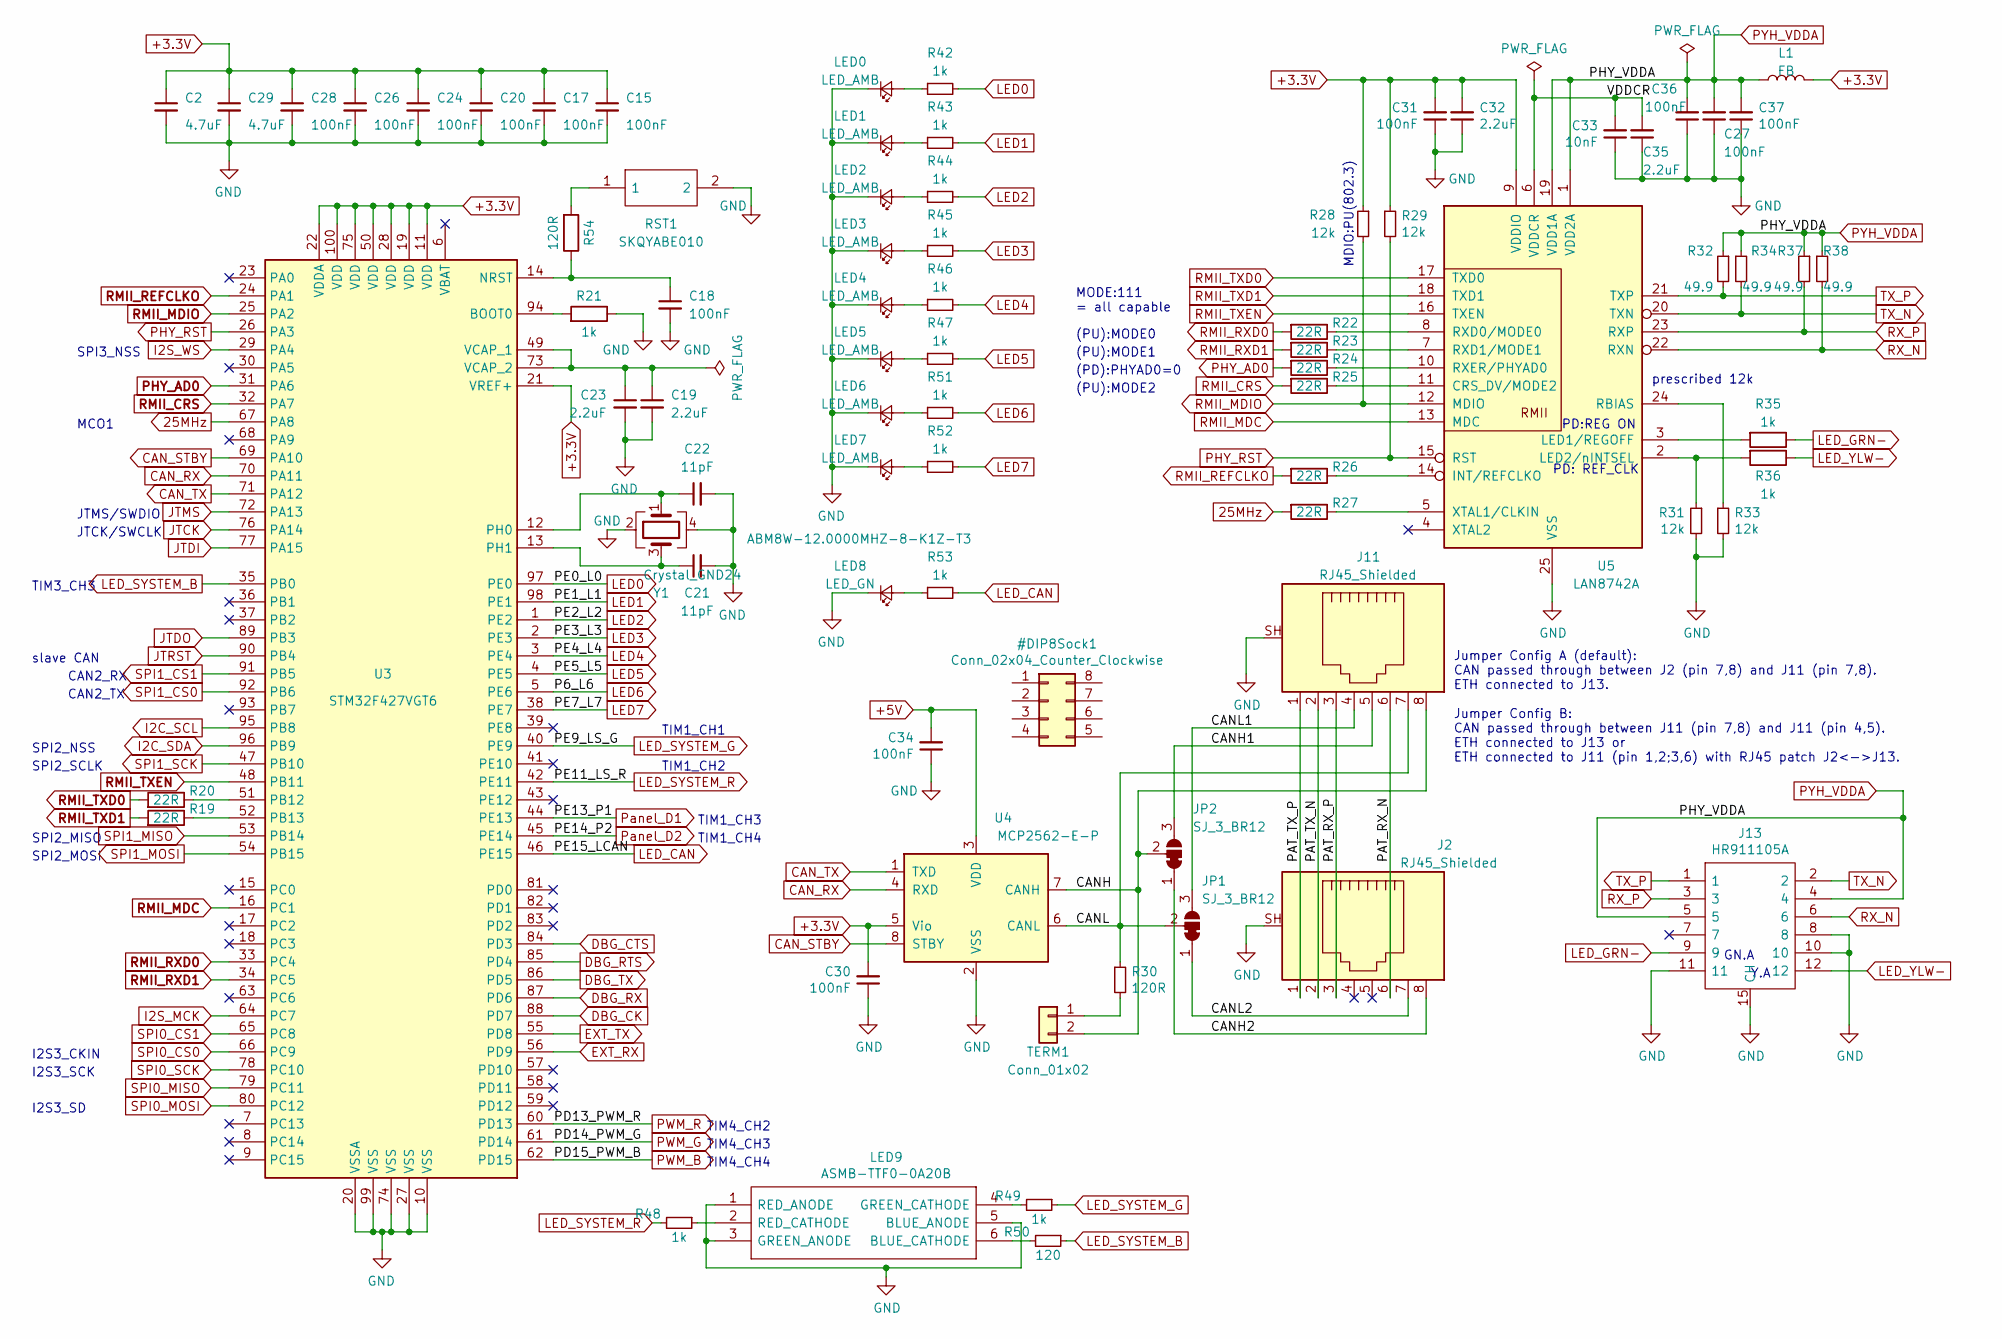
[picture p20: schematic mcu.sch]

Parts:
C2, C29: 4.7uF; C_0805_2012Metric; MPN GRM21BR71A475KE51L; Mouser 81-GRM21BR71A475KE1L
C15, C17, C18, C20, C24, C26, C27, C28, C30, C31, C34, C36, C37: 100nF; C_0603_1608Metric; MPN C0603C104K5RECAUTO; Mouser 80-C0603C104K5REAUTO
C19, C23, C32, C35: 2.2uF; C_0603_1608Metric; MPN C0603C225K9RACTU; Mouser 80-C0603C225K9R
C21, C22: 11pF; C_0603_1608Metric; MPN CBR06C110F5GAC; Mouser 80-CBR06C110F5G
C33: 10nF; C_0603_1608Metric; MPN C0603C103K1REAUTO; Mouser 80-C0603C103K1REAUTO
J2, J11: RJ45_Shielded; RJ45_Amphenol_RJHSE5380; MPN RJHSE-5380; Mouser 523-RJHSE-5380
J13: HR911105A; HR911105A_1; Manufacturer_Part_Number HR911105A; Mouser 710-7499011121A (WE near match)
JP1, JP2: SJ_3_BR12; SolderJumper-3_P1.3mm_Bridged12_RoundedPad1.0x1.5mm
L1: FB; L_0603_1608Metric; MPN BLM18KG121TN1D; Mouser 81-BLM18KG121TN1D
LED0, LED1, LED2, LED3, LED4, LED5, LED6, LED7: LED_AMB; LED_0603_1608Metric_Castellated; MPN LTST-C190AKT; Mouser 859-LTST-C190AKT
LED8: LED_GN; LED_0603_1608Metric_Castellated; MPN LTST-C190KGKT; Mouser 859-LTST-C190KGKT
LED9: ASMB-TTF0-0A20B; ASMBTTF00A20B; Manufacturer_Part_Number ASMB-TTF0-0A20B; Mouser Part Number 630-ASMB-TTF0-0A20B
R19, R20, R22, R23, R24, R25, R26, R27: 22R; R_0603_1608Metric; MPN RC0603JR-0722RL; Mouser 603-RC0603JR-0722RL
R21, R35, R36, R42, R43, R44, R45, R46, R47, R49, R51, R52, R53: 1k; R_0603_1608Metric; MPN RC0603FR-071KL; Mouser 603-RC0603FR-071KL
R28, R29, R31, R33: 12k; R_0603_1608Metric; MPN RC0603FR-0712KL; Mouser 603-RC0603FR-0712KL
R30, R54: 120R; R_0603_1608Metric; MPN RC0603FR-07120RL; Mouser 603-RC0603FR-07120RL
R32, R34, R37, R38: 49.9; R_0603_1608Metric; MPN RC0603FR-0749R9L; Mouser 603-RC0603FR-0749R9L
R48: 1k; R_0603_1608Metric; MPN RC0603FR-07120RL; Mouser 603-RC0603FR-07120RL
R50: 120; R_0603_1608Metric; MPN RC0603FR-071KL; Mouser 603-RC0603FR-071KL
RST1: SKQYABE010; Manufacturer_Part_Number SKQYABE010; Mouser 688-SKQYAB
TERM1: Conn_01x02; PinHeader_1x02_P2.54mm_Vertical; MPN S2B-PH-K-S(LF)(SN)‎; DigiKey 455-1719-ND
U3: STM32F427VGT6; LQFP-100_14x14mm_P0.5mm; MPN STM32F427VGT6; Mouser 511-STM32F427VGT6
U4: MCP2562-E-P; DIP-8_W7.62mm_Socket; MPN MCP2562-E/P; Mouser 579-MCP2562-E/P
U5: LAN8742A; QFN-24-1EP_4x4mm_P0.5mm_EP2.6x2.6mm; MPN LAN8742A-CZ-TR; Mouser 579-LAN8742A-CZ-TR
Y1: Crystal_GND24; Crystal_SMD_Abracon_ABM8G-4Pin_3.2x2.5mm; MPN ABM8W-12.0000MHZ-8-K1Z-T3; Mouser 815-8W12-8K1ZT

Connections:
25MHz: R27.2, U3.67 (PA8)
+3.3V: C2.1, C15.1, C17.1, C20.1, C24.1, C26.1, C28.1, C29.1, C30.2, C31.2, C32.2, L1.2, R28.1, R29.1, U3.11 (VDD), U3.19 (VDD), U3.21 (VREF+), U3.22 (VDDA), U3.28 (VDD), U3.50 (VDD), U3.75 (VDD), U3.100 (VDD), U4.5 (Vio), U5.9 (VDDIO); also elsewhere on the board
+5V: C34.2, U4.3 (VDD); also elsewhere on the board
/MCU/CANH: J11.8, JP2.2 (C), TERM1.2, U4.7 (CANH)
/MCU/CANH1: J11.5, JP2.3 (B)
/MCU/CANH2: J2.8, JP2.1 (A)
/MCU/CANL: J11.7, JP1.2 (C), R30.1, U4.6 (CANL)
/MCU/CANL1: J11.4, JP1.3 (B)
/MCU/CANL2: J2.7, JP1.1 (A)
/MCU/PAT_RX_N: J2.6, J11.6
/MCU/PAT_RX_P: J2.3, J11.3
/MCU/PAT_TX_N: J2.2, J11.2
/MCU/PAT_TX_P: J2.1, J11.1
/MCU/VDDCR: C33.2, C35.2, U5.6 (VDDCR)
CAN_RX: U3.70 (PA11), U4.4 (RXD)
CAN_STBY: U3.69 (PA10), U4.8 (STBY)
CAN_TX: U3.71 (PA12), U4.1 (TXD)
DBG_CK: U3.88 (PD7); also elsewhere on the board
DBG_CTS: U3.84 (PD3); also elsewhere on the board
DBG_RTS: U3.85 (PD4); also elsewhere on the board
DBG_RX: U3.87 (PD6); also elsewhere on the board
DBG_TX: U3.86 (PD5); also elsewhere on the board
EXT_RX: U3.56 (PD9); also elsewhere on the board
EXT_TX: U3.55 (PD8); also elsewhere on the board
GND: C2.2, C15.2, C17.2, C18.2, C19.2, C20.2, C21.2, C22.2, C23.2, C24.2, C26.2, C27.1, C28.2, C29.2, C30.1, C31.1, C32.1, C33.1, C34.1, C35.1, C36.1, C37.1, J2.SH, J11.SH, J13.8, J13.10, J13.11, J13.15 (CH), J13.16 (CH), LED0.1 (K), LED1.1 (K), LED2.1 (K), LED3.1 (K), LED4.1 (K), LED5.1 (K), LED6.1 (K), LED7.1 (K), LED8.1 (K), LED9.1 (RED_ANODE), LED9.3 (GREEN_ANODE), LED9.5 (BLUE_ANODE), R21.1, R31.2, R33.2, RST1.2, U3.10 (VSS), U3.20 (VSSA), U3.27 (VSS), U3.74 (VSS), U3.99 (VSS), U4.2 (VSS), U5.25 (VSS), Y1.2, Y1.4; also elsewhere on the board
I2C_SCL: U3.95 (PB8); also elsewhere on the board
I2C_SDA: U3.96 (PB9); also elsewhere on the board
I2S_MCK: U3.64 (PC7); also elsewhere on the board
I2S_WS: U3.29 (PA4); also elsewhere on the board
JTCK: U3.76 (PA14); also elsewhere on the board
JTDI: U3.77 (PA15); also elsewhere on the board
JTDO: U3.89 (PB3); also elsewhere on the board
JTMS: U3.72 (PA13); also elsewhere on the board
JTRST: U3.90 (PB4); also elsewhere on the board
LED0: R42.2, U3.97 (PE0)
LED1: R43.2, U3.98 (PE1)
LED2: R44.2, U3.1 (PE2)
LED3: R45.2, U3.2 (PE3)
LED4: R46.2, U3.3 (PE4)
LED5: R47.2, U3.4 (PE5)
LED6: R51.2, U3.5 (PE6)
LED7: R52.2, U3.38 (PE7)
LED_CAN: R53.2, U3.46 (PE15)
LED_GRN-: J13.9, R35.1
LED_SYSTEM_B: R50.1, U3.35 (PB0)
LED_SYSTEM_G: R49.1, U3.40 (PE9)
LED_SYSTEM_R: R48.2, U3.42 (PE11)
LED_YLW-: J13.12, R36.1
unnamed: C18.1, R54.1, U3.14 (NRST)
unnamed: C19.1, C23.1, U3.49 (VCAP_1), U3.73 (VCAP_2)
unnamed: C21.1, U3.13 (PH1), Y1.3
unnamed: C22.1, U3.12 (PH0), Y1.1
unnamed: LED0.2 (A), R42.1
unnamed: LED1.2 (A), R43.1
unnamed: LED2.2 (A), R44.1
unnamed: LED3.2 (A), R45.1
unnamed: LED4.2 (A), R46.1
unnamed: LED5.2 (A), R47.1
unnamed: LED6.2 (A), R51.1
unnamed: LED7.2 (A), R52.1
unnamed: LED8.2 (A), R53.1
unnamed: LED9.2 (RED_CATHODE), R48.1
unnamed: LED9.4 (GREEN_CATHODE), R49.2
unnamed: LED9.6 (BLUE_CATHODE), R50.2
unnamed: R19.1, U3.52 (PB13)
unnamed: R20.1, U3.51 (PB12)
unnamed: R21.2, U3.94 (BOOT0)
unnamed: R22.1, U5.8 (RXD0/MODE0)
unnamed: R23.1, U5.7 (RXD1/MODE1)
unnamed: R24.1, U5.10 (RXER/PHYAD0)
unnamed: R25.1, U5.11 (CRS_DV/MODE2)
unnamed: R26.1, U5.14 (INT/REFCLKO)
unnamed: R27.1, U5.5 (XTAL1/CLKIN)
unnamed: R30.2, TERM1.1
unnamed: R31.1, R36.2, U5.2 (LED2/nINTSEL)
unnamed: R33.1, U5.24 (RBIAS)
unnamed: R35.2, U5.3 (LED1/REGOFF)
unnamed: R54.2, RST1.1
PHY_AD0: R24.2, U3.31 (PA6)
PHY_RST: R29.2, U3.26 (PA3), U5.15 (RST)
PWM_B: U3.62 (PD15); also elsewhere on the board
PWM_G: U3.61 (PD14); also elsewhere on the board
PWM_R: U3.60 (PD13); also elsewhere on the board
PYH_VDDA: C27.2, C36.2, C37.2, J13.4, J13.5, L1.1, R32.1, R34.1, R37.1, R38.1, U5.1 (VDD2A), U5.19 (VDD1A)
Panel_D1: U3.44 (PE13); also elsewhere on the board
Panel_D2: U3.45 (PE14); also elsewhere on the board
RMII_CRS: R25.2, U3.32 (PA7)
RMII_MDC: U3.16 (PC1), U5.13 (MDC)
RMII_MDIO: R28.2, U3.25 (PA2), U5.12 (MDIO)
RMII_REFCLKO: R26.2, U3.24 (PA1)
RMII_RXD0: R22.2, U3.33 (PC4)
RMII_RXD1: R23.2, U3.34 (PC5)
RMII_TXD0: R20.2, U5.17 (TXD0)
RMII_TXD1: R19.2, U5.18 (TXD1)
RMII_TXEN: U3.48 (PB11), U5.16 (TXEN)
RX_N: J13.6, R38.2, U5.22 (RXN)
RX_P: J13.3, R37.2, U5.23 (RXP)
SPI0_CS0: U3.66 (PC9); also elsewhere on the board
SPI0_CS1: U3.65 (PC8); also elsewhere on the board
SPI0_MISO: U3.79 (PC11); also elsewhere on the board
SPI0_MOSI: U3.80 (PC12); also elsewhere on the board
SPI0_SCK: U3.78 (PC10); also elsewhere on the board
SPI1_CS0: U3.92 (PB6); also elsewhere on the board
SPI1_CS1: U3.91 (PB5); also elsewhere on the board
SPI1_MISO: U3.53 (PB14); also elsewhere on the board
SPI1_MOSI: U3.54 (PB15); also elsewhere on the board
SPI1_SCK: U3.47 (PB10); also elsewhere on the board
TX_N: J13.2, R34.2, U5.20 (TXN)
TX_P: J13.1, R32.2, U5.21 (TXP)

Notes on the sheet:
MCO1
prescribed 12k
PD:REG ON
PD: REF_CLK
MDIO:PU(802.3)
(PU):MODE0
(PU):MODE1
(PU):MODE2
(PD):PHYAD0=0
MODE:111 = all capable
GN.A
Y.A
JTMS/SWDIO
JTCK/SWCLK
CAN2_RX
CAN2_TX
slave CAN
I2S3_SD
I2S3_SCK
I2S3_CKIN
SPI3_NSS
SPI2_SCLK
SPI2_MOSI
SPI2_MISO
SPI2_NSS
TIM1_CH3
TIM1_CH4
TIM4_CH2
TIM4_CH3
TIM4_CH4
TIM3_CH3
TIM1_CH1
TIM1_CH2
Jumper Config A (default): CAN passed through between J2 (pin 7,8) and J11 (pin 7,8). ETH connected to J13. Jumper Config B: CAN passed through between J11 (pin 7,8) and J11 (pin 4,5). ETH connected to J13 or ETH connected to J11 (pin 1,2;3,6) with RJ45 patch J2<->J13.

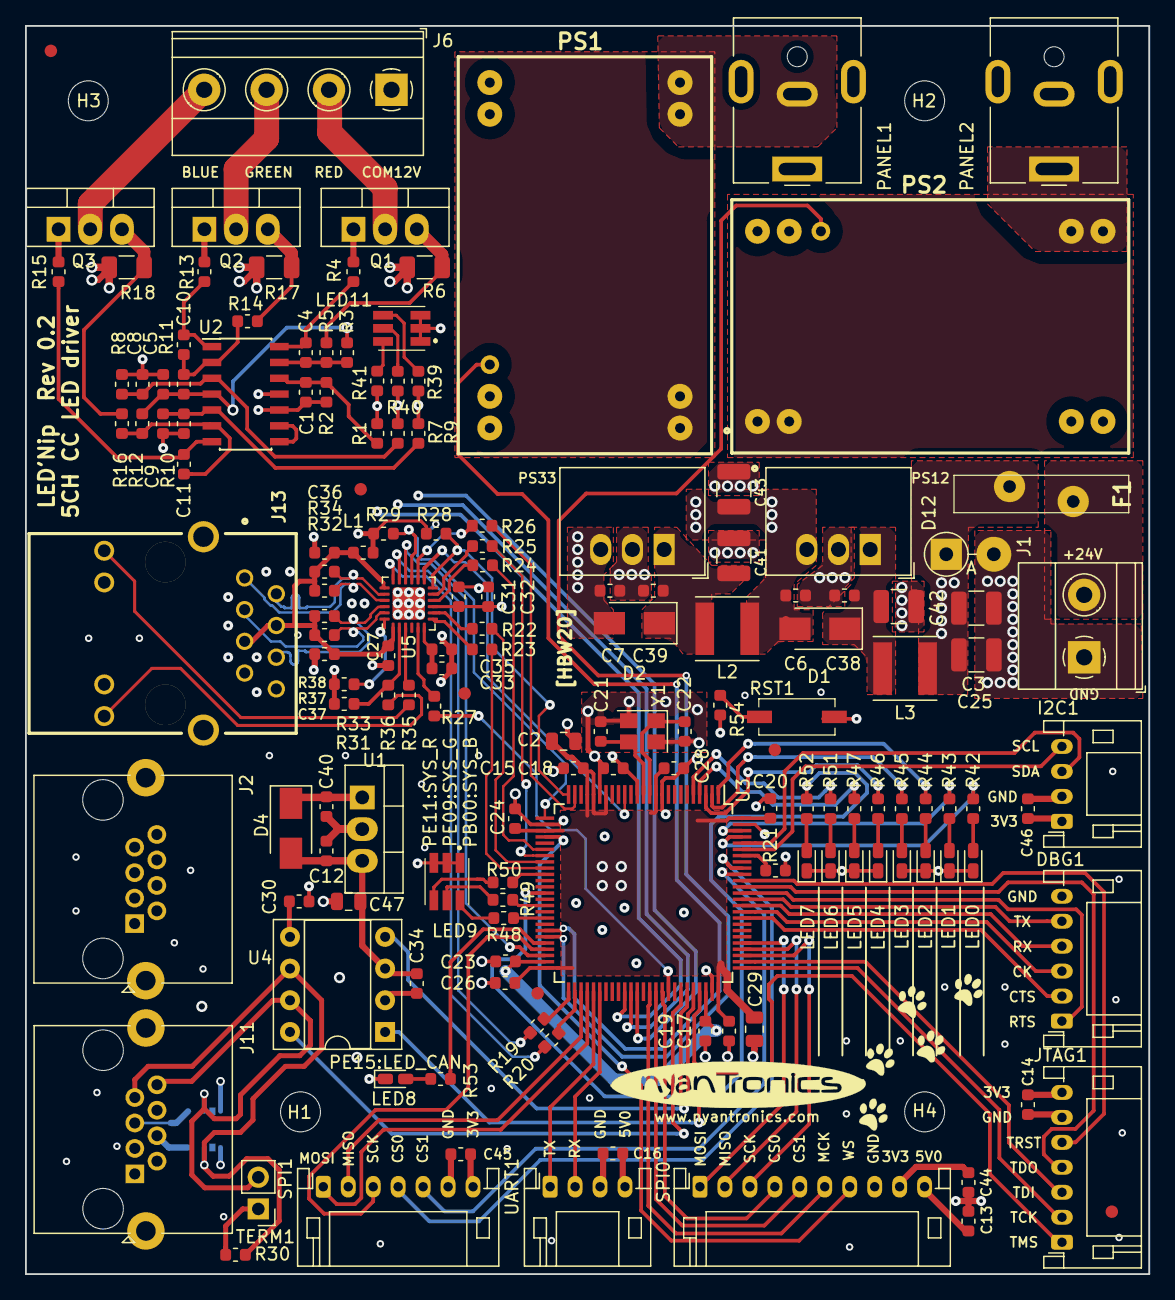
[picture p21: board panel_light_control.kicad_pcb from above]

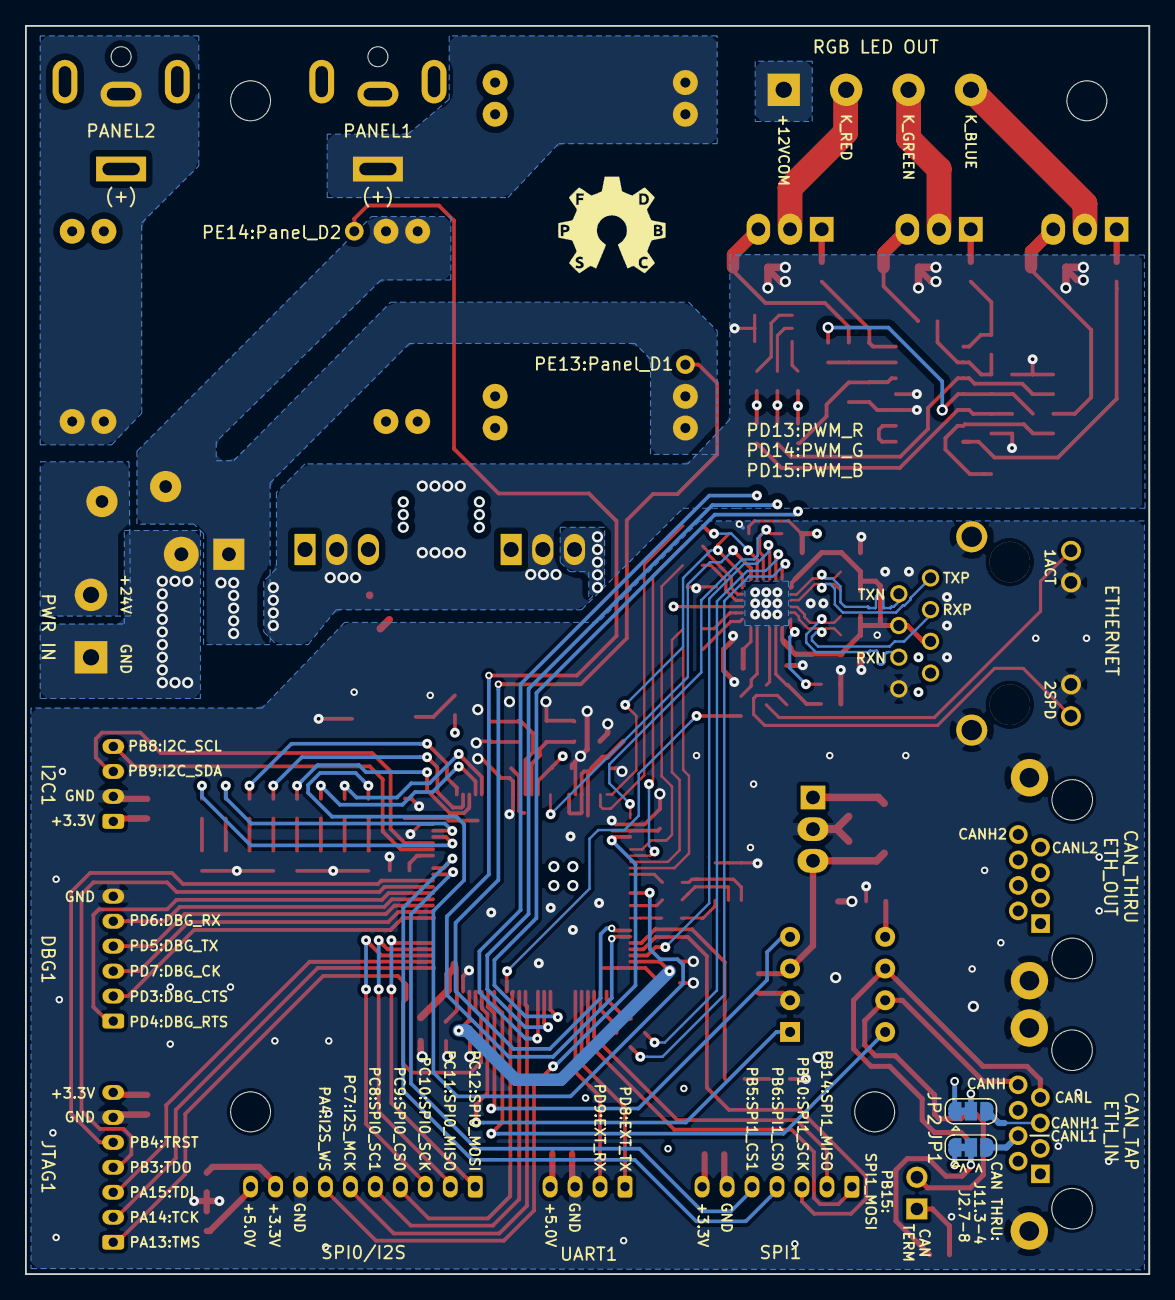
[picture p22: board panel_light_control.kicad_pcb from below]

Board: 4 copper layers, 90.0 x 100.0 mm, 160 parts (2 on the bottom side), 140 nets.

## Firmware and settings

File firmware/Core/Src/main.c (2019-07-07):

/**
  ******************************************************************************
  * @file           : main.c
  * @brief          : Main program body
  ******************************************************************************
  * This notice applies to any and all portions of this file
  * that are not between comment pairs USER CODE BEGIN and
  * USER CODE END. Other portions of this file, whether 
  * inserted by the user or by software development tools
  * are owned by their respective copyright owners.
  *
  * Copyright (c) 2019 STMicroelectronics International N.V. 
  * All rights reserved.
  *
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
  ******************************************************************************
  */
/* Includes ------------------------------------------------------------------*/
#include "main.h"
#include "stm32f4xx_hal.h"
#include "lwip.h"

/* USER CODE BEGIN Includes */
#include <math.h>
/* USER CODE END Includes */

CAN_HandleTypeDef hcan1;

I2C_HandleTypeDef hi2c1;

SPI_HandleTypeDef hspi2;
SPI_HandleTypeDef hspi3;

TIM_HandleTypeDef htim1;
TIM_HandleTypeDef htim3;
TIM_HandleTypeDef htim4;

UART_HandleTypeDef huart2;
UART_HandleTypeDef huart3;

/* USER CODE BEGIN PV */

typedef struct RGB_DUTY_RAW {
	uint16_t r, g, b;
} RGB_DUTY_RAW;

typedef struct PANEL_DUTY_RAW {
	uint16_t p1, p2;
} PANEL_DUTY_RAW;

static volatile RGB_DUTY_RAW syst_led_pwm; // PWM values for the onboard LED (duty cycle rel. to PWM_TIMER_RELOAD)
static volatile RGB_DUTY_RAW ext_led_pwm;  // PWM values for three external LED channels (duty cycle rel. to PWM_TIMER_RELOAD)
static volatile PANEL_DUTY_RAW panel_pwm;  // PWM values for two onboard CC drivers (duty cycle rel. to PWM_TIMER_RELOAD)
/* USER CODE END PV */

void SystemClock_Config(void);
static void MX_GPIO_Init(void);
static void MX_CAN1_Init(void);
static void MX_I2C1_Init(void);
static void MX_SPI2_Init(void);
static void MX_SPI3_Init(void);
static void MX_TIM1_Init(void);
static void MX_TIM3_Init(void);
static void MX_TIM4_Init(void);
static void MX_USART2_UART_Init(void);
static void MX_USART3_UART_Init(void);

void HAL_TIM_MspPostInit(TIM_HandleTypeDef *htim);
                                
                                
                                

/* USER CODE BEGIN PFP */

void update_syst_pwm(void);
void update_ext_pwm(void); 
void update_panel_pwm(void);


// --- crusty HSV/RGB stuff ahead.
typedef struct RgbColor {
    unsigned char r;
    unsigned char g;
    unsigned char b;
} RgbColor;

typedef struct HsvColor {
    unsigned char h;
    unsigned char s;
    unsigned char v;
} HsvColor;

RgbColor HsvToRgb(HsvColor hsv) {
    RgbColor rgb;
    unsigned char region, remainder, p, q, t;

    if (hsv.s == 0) {
        rgb.r = hsv.v;
        rgb.g = hsv.v;
        rgb.b = hsv.v;
        return rgb;
    }

    region = hsv.h / 43;
    remainder = (hsv.h - (region * 43)) * 6; 

    p = (hsv.v * (255 - hsv.s)) >> 8;
    q = (hsv.v * (255 - ((hsv.s * remainder) >> 8))) >> 8;
    t = (hsv.v * (255 - ((hsv.s * (255 - remainder)) >> 8))) >> 8;

    switch (region) {
        case 0:
            rgb.r = hsv.v; rgb.g = t; rgb.b = p;
            break;
        case 1:
            rgb.r = q; rgb.g = hsv.v; rgb.b = p;
            break;
        case 2:
            rgb.r = p; rgb.g = hsv.v; rgb.b = t;
            break;
        case 3:
            rgb.r = p; rgb.g = q; rgb.b = hsv.v;
            break;
        case 4:
            rgb.r = t; rgb.g = p; rgb.b = hsv.v;
            break;
        default:
            rgb.r = hsv.v; rgb.g = p; rgb.b = q;
            break;
    }

    return rgb;
}

HsvColor RgbToHsv(RgbColor rgb) {
    HsvColor hsv;
    unsigned char rgbMin, rgbMax;

    rgbMin = rgb.r < rgb.g ? (rgb.r < rgb.b ? rgb.r : rgb.b) : (rgb.g < rgb.b ? rgb.g : rgb.b);
    rgbMax = rgb.r > rgb.g ? (rgb.r > rgb.b ? rgb.r : rgb.b) : (rgb.g > rgb.b ? rgb.g : rgb.b);

    hsv.v = rgbMax;
    if (hsv.v == 0) {
        hsv.h = 0;
        hsv.s = 0;
        return hsv;
    }

    hsv.s = 255 * ((long) rgbMax - (long) rgbMin) / hsv.v;
    if (hsv.s == 0) {
        hsv.h = 0;
        return hsv;
    }

    if (rgbMax == rgb.r) {  hsv.h = 0 + 43 * (rgb.g - rgb.b) / (rgbMax - rgbMin); }
    else if (rgbMax == rgb.g) { hsv.h = 85 + 43 * (rgb.b - rgb.r) / (rgbMax - rgbMin); }
    else { hsv.h = 171 + 43 * (rgb.r - rgb.g) / (rgbMax - rgbMin); }

    return hsv;
}


static HsvColor LedHsv;
static RgbColor LedRgb;
// --- end of crusty HSV/RGB stuff


//void HAL_TIM_PeriodElapsedCallback(TIM_HandleTypeDef *htim) {
   /*  if (htim->Instance == TIM5)
    {
        count2++;
    } */
	
	// The duty cycle value is a percentage of the reload register value (ARR). Rounding is used.
	/* if (pwm0 > 100.0F) { pwm0 = 0.0F; }
	float DC = pwm0;
	pwm0 += 0.5F; */
	
    //uint32_t newRegVal = (uint32_t) roundf((float)(htim1.Instance->ARR) * (DC * 0.01F));

    //In case of the DC being calculated as higher than the reload register, cap it to the reload register*/
    /* if (newRegVal > htim1.Instance->ARR){
        newRegVal = htim1.Instance->ARR;
    } */

    ///Assign the new DC count to the capture compare register.
     //htim1.Instance->CCR3 = (uint32_t)(roundf(newRegVal));  /*Change CCR1 to appropriate channel, or pass it in with function.*/ 
//}


/* USER CODE END PFP */

/* USER CODE BEGIN 0 */

inline void update_syst_pwm(void) {
	/* LED_SYSTEM_R, LED_SYSTEM_G, LED_SYSTEM_B: 
		the PWM signals for the external three LED channels are mapped to TIM1 and TIM3 channels due to 
		peripheral mapping and routing constraints.
		TIM1 and TIM3 output polarities are normal, duty cycle is 100% * TIMn->CCRn / TIMn->ARR.
	*/
	__HAL_TIM_SET_COMPARE(&htim1, TIM_CHANNEL_2, syst_led_pwm.r);
	__HAL_TIM_SET_COMPARE(&htim1, TIM_CHANNEL_1, syst_led_pwm.g);
	// note the B channel is driven by TIM3. It also needs to be configured to use the same counting mode.
	__HAL_TIM_SET_COMPARE(&htim3, TIM_CHANNEL_3, syst_led_pwm.b);	
} 

inline void update_ext_pwm(void) {
	/* PWM_R, PWM_G, PWM_B: 
		the PWM signals for the external three LED channels are mapped to TIM4 channels 2, 3 and 4.
		TIM4 output polarity is normal, duty cycle is 100% * TIM4->CCRn / TIM4->ARR.
	*/
	__HAL_TIM_SET_COMPARE(&htim4, TIM_CHANNEL_2, ext_led_pwm.r);
	__HAL_TIM_SET_COMPARE(&htim4, TIM_CHANNEL_3, ext_led_pwm.g);
	__HAL_TIM_SET_COMPARE(&htim4, TIM_CHANNEL_4, ext_led_pwm.b);	
} 

inline void update_panel_pwm(void) {
	/* Panel_D1: 
		TIM_CHANNEL_3 output polarity is normal, duty cycle is 100% * TIM1->CCR3 / TIM1->ARR.
	*/
	__HAL_TIM_SET_COMPARE(&htim1, TIM_CHANNEL_3, panel_pwm.p1);
	/* Panel_D2: 
		TIM_CHANNEL_4 output polarity is inverted (TIM1_OCPOLARITY_LOW) and the duty cycle is made complementary.
		Combined with TIM_OCPOLARITY_LOW, the two channels (CH3 and CH4) produce 180° interleaved PWM 
		to minimize primary-side current ripple and audible noise.
	*/
	__HAL_TIM_SET_COMPARE(&htim1, TIM_CHANNEL_4, TIM1->ARR - panel_pwm.p2); 
} 


// --- MQTT begins here ---
#include <string.h>
#include "mqtt.h"

#define MQTT_HOST_0 10
#define MQTT_HOST_1 214
#define MQTT_HOST_2 227
#define MQTT_HOST_3 218
//#define MQTT_HOST "vielseitigkeit.club.entropia.de"
//#define MQTT_HOST "localhost"
#define MQTT_PORT 1883
#define MQTT_USERNAME "user"
#define MQTT_KEY "pass"

mqtt_client_t static_client;
int16_t RgbToPwm = PWM_TIMER_RELOAD / 360; // Limit the max brightness/current this way. 

void mqtt_do_connect(mqtt_client_t *client);


// --- Callbacks ---
//


static int inpub_id;
static void mqtt_incoming_publish_cb(void *arg, const char *topic, u32_t tot_len) {
	printf("Incoming publish at topic %s with total length %u\n", topic, (unsigned int)tot_len);

	/* Decode topic string into a user defined reference */
	if(strcmp(topic, "/plants/rgb") == 0) {
		inpub_id = 0;
	} 
	else if (strcmp(topic, "/plants/panels") == 0) {
		inpub_id = 1;
	}	 
	else {
		/* For all other topics */
		inpub_id = 2;
	}
}


static void mqtt_sub_request_cb(void *arg, err_t result) {
	  /* Just print the result code here for simplicity, 
		 normal behaviour would be to take some action if subscribe fails like 
		 notifying user, retry subscribe or disconnect from server */
	  printf("Subscribe result: %d\n", result);
}


static void mqtt_request_cb(void *arg, err_t result) {
	//
}


static void mqtt_incoming_data_cb(void *arg, const u8_t *data, u16_t len, u8_t flags) {
	printf("Incoming publish payload with length %d, flags %u\n", len, (unsigned int)flags);
	//mqtt_publish(&static_client, "/plants/debug", "Red adjusted.", 12, 0, 0, mqtt_request_cb, 0);

	if (flags & MQTT_DATA_FLAG_LAST) {
		/* Last fragment of payload received (or whole part if payload fits receive buffer
		See MQTT_VAR_HEADER_BUFFER_LEN)  */

		/* Call function or do action depending on reference, in this case inpub_id */
		if (inpub_id == 0) { // /plants/rgb
		  /* Don't trust the publisher, check zero termination */
			if (data[len-1] == 0) {
				printf("mqtt_incoming_data_cb: %s\n", (const char *) data);
				//mqtt_publish(&static_client, "/plants/debug", "Red adjusted.", 12, 0, 0, mqtt_request_cb, 0);
			}
			
			if (len == 2) {
				if ((char) data[0] == 'R') {
					ext_led_pwm.r = (char) data[1];
					ext_led_pwm.r *= 3;
					mqtt_publish(&static_client, "/plants/debug", "Red adjusted.", 12, 0, 0, mqtt_request_cb, 0);
				}
				else if ((char) data[0] == 'G') {
					ext_led_pwm.g = (char) data[1];
					ext_led_pwm.g *= 3;
					mqtt_publish(&static_client, "/plants/debug", "Green adjusted.", 14, 0, 0, mqtt_request_cb, 0);
				}
				else if ((char) data[0] == 'B') {
					ext_led_pwm.b = (char) data[1];
					ext_led_pwm.b *= 3;
					mqtt_publish(&static_client, "/plants/debug", "Blue adjusted.", 13, 0, 0, mqtt_request_cb, 0);
				}
				
				update_ext_pwm();
			}
			else {
				mqtt_publish(&static_client, "/plants/debug", "No valid RGB command.", 21, 0, 0, mqtt_request_cb, 0);
			}
		} 
		else if (inpub_id == 1) { // /plants/panels
			if (len == 2) {
				if ((char) data[0] == 'W') {
					panel_pwm.p1 = (char) data[1];
					panel_pwm.p1 *= 3;
				}
				else if ((char) data[0] == 'Y') {
					panel_pwm.p2 = (char) data[1];
					panel_pwm.p2 *= 3;
				}
				
				update_panel_pwm();
			}
		} 
		else {
			printf("mqtt_incoming_data_cb: Ignoring payload...\n");
		}
	} 
	else {
		/* Handle fragmented payload, store in buffer, write to file or whatever */
	}
}


static void mqtt_connection_cb(mqtt_client_t *client, void *arg, mqtt_connection_status_t status) {
	err_t err;
	if (status == MQTT_CONNECT_ACCEPTED) {
		printf("mqtt_connection_cb: Successfully connected\n");

		/* Setup callback for incoming publish requests */
		mqtt_set_inpub_callback(client, mqtt_incoming_publish_cb, mqtt_incoming_data_cb, arg);

		/* Subscribe to a topic named "subtopic" with QoS level 1, call mqtt_sub_request_cb with result */ 
		err = mqtt_subscribe(client, "/plants/rgb", 1, mqtt_sub_request_cb, arg);
		err = mqtt_subscribe(client, "/plants/panels", 1, mqtt_sub_request_cb, arg);

		if (err != ERR_OK) {
			printf("mqtt_subscribe return: %d\n", err);
		}
	} 
	else {
		printf("mqtt_connection_cb: Disconnected, reason: %d\n", status);

		/* Its more nice to be connected, so try to reconnect */
		mqtt_do_connect(client);
	}  
}
// --- End Callbacks ---


void mqtt_do_connect(mqtt_client_t *client) {
	ip4_addr_t broker_ipaddr;
	struct mqtt_connect_client_info_t ci;
	err_t err;

	/* Setup an empty client info structure */
	memset(&ci, 0, sizeof(ci));

	/* Minimal amount of information required is client identifier, so set it here */ 
	ci.client_id = "LEDNip-Mark_I";
	
	IP4_ADDR(&broker_ipaddr, MQTT_HOST_0, MQTT_HOST_1, MQTT_HOST_2, MQTT_HOST_3);

	/* Initiate client and connect to server, if this fails immediately an error code is returned
	 otherwise mqtt_connection_cb will be called with connection result after attempting 
	 to establish a connection with the server. 
	 For now MQTT version 3.1.1 is always used */
	err = mqtt_client_connect(client, &broker_ipaddr, MQTT_PORT, mqtt_connection_cb, 0, &ci);

	/* For now just print the result code if something goes wrong */
	if(err != ERR_OK) {
		printf("mqtt_connect return %d\n", err);
	}
}


/* USER CODE END 0 */

/**
  * @brief  The application entry point.
  *
  * @retval None
  */
int main(void) {
  /* MCU Configuration----------------------------------------------------------*/

  /* Reset of all peripherals, Initializes the Flash interface and the Systick. */
  HAL_Init();

  /* Configure the system clock */
  SystemClock_Config();

  /* Initialize all configured peripherals */
  MX_GPIO_Init();
  MX_CAN1_Init();
  MX_I2C1_Init();
  MX_SPI2_Init();
  MX_SPI3_Init();
  MX_TIM1_Init();
  MX_TIM3_Init();
  MX_TIM4_Init();
  MX_USART2_UART_Init();
  MX_USART3_UART_Init();
  MX_LWIP_Init();
  /* USER CODE BEGIN 2 */
  
  // Start all of the PWM channels.
  if (HAL_TIM_PWM_Start(&htim1, TIM_CHANNEL_1) != HAL_OK)   {
    Error_Handler();
  }
  
  if (HAL_TIM_PWM_Start(&htim1, TIM_CHANNEL_2) != HAL_OK)   {
    Error_Handler();
  }
  
  if (HAL_TIM_PWM_Start(&htim1, TIM_CHANNEL_3) != HAL_OK)   {
    Error_Handler();
  }
  
  if (HAL_TIM_PWM_Start(&htim1, TIM_CHANNEL_4) != HAL_OK)   {
    Error_Handler();
  }
  
  if (HAL_TIM_PWM_Start(&htim3, TIM_CHANNEL_3) != HAL_OK)   {
    Error_Handler();
  }
  
  if (HAL_TIM_PWM_Start(&htim4, TIM_CHANNEL_2) != HAL_OK)   {
    Error_Handler();
  }
  
  if (HAL_TIM_PWM_Start(&htim4, TIM_CHANNEL_3) != HAL_OK)   {
    Error_Handler();
  }
  
  if (HAL_TIM_PWM_Start(&htim4, TIM_CHANNEL_4) != HAL_OK)   {
    Error_Handler();
  }
  
  // Start timer for the LED update function.
  //TIM2_Init();
  
  // Compute the prescaler value to have TIM3 counter clock equal to 10 KHz
  //uwPrescalerValue = (uint32_t) ((SystemCoreClock) / 10000) - 1;
  
  /* Set TIMx instance */
  //htim2.Instance = TIM2;
   
  /* Initialize TIM2 peripheral as follows:
       + Period = 10000 - 1
       + Prescaler = ((SystemCoreClock/2)/10000) - 1
       + ClockDivision = 0
       + Counter direction = Up
  */
  //htim2.Init.Period = 10000 - 1;
 /*  htim2.Init.Period = 500; // 62499;
  //htim2.Init.Prescaler = uwPrescalerValue;
  htim2.Init.Prescaler = 40000; //((SystemCoreClock/2)/10000) - 1; // 319;
  htim2.Init.ClockDivision = 0;
  htim2.Init.CounterMode = TIM_COUNTERMODE_UP;
  if(HAL_TIM_Base_Init(&htim2) != HAL_OK) {
    Error_Handler();
  } */
  
  /*##-2- Start the TIM Base generation in interrupt mode ####################*/
  /* Start Channel1 */
  /* if(HAL_TIM_Base_Start_IT(&htim2) != HAL_OK)
  {
    Error_Handler();
  } */

 	/* int16_t pwm_value = 0;
	int16_t step = 5;
	
	LedHsv.h = 0;
	LedHsv.s = 0xff;
	LedHsv.v = 0xff;
	int16_t HsvStep = 1;
	int16_t HsvStepDelayCounter = 0;
	int8_t HsvStepLinger = 0; */
	
	// --- MQTT stuff ---
	mqtt_do_connect(&static_client);
  
  /* USER CODE END 2 */

  /* Infinite loop */
  /* USER CODE BEGIN WHILE */
  while (1) {

  /* USER CODE END WHILE */

  /* USER CODE BEGIN 3 */
  
		MX_LWIP_Process();

		/*Assign the new DC count to the capture compare register.*/
		
		/* if (pwm_value <= 0) {
			step =  5;
		}
		if (pwm_value >= PWM_TIMER_RELOAD) {
			step = -5;
		}
		
		pwm_value += step; */
		 
		// brightness ramp demo
		// __HAL_TIM_SET_COMPARE(&htim1, TIM_CHANNEL_3, pwm_value*pwm_value / PWM_TIMER_RELOAD);
		// __HAL_TIM_SET_COMPARE(&htim1, TIM_CHANNEL_4, pwm_value*pwm_value / PWM_TIMER_RELOAD);
		
		// colour temperature modulation demo
		//__HAL_TIM_SET_COMPARE(&htim1, TIM_CHANNEL_3, pwm_value);
		//__HAL_TIM_SET_COMPARE(&htim1, TIM_CHANNEL_4, PWM_TIMER_RELOAD - (PWM_TIMER_RELOAD - pwm_value)); // CH4 output polarity is inverted in software so it needs the complementary duty cycle value		
		/* panel_pwm.p1 = pwm_value;
		panel_pwm.p2 = PWM_TIMER_RELOAD - pwm_value;
		update_panel_pwm(); */
		
		// Demo: cycle through the RGB colours by mapping from the HSV colour space.
		/* if (HsvStepDelayCounter >= 10) {
			if (LedHsv.h >= 0xff && HsvStepLinger == 0) { HsvStep = -1; HsvStepLinger = 2; }
			else if (LedHsv.h <= 0x00 && HsvStepLinger == 0) { HsvStep = 1; HsvStepLinger = 2; }
			else if (HsvStepLinger == 2) { HsvStepLinger = 1; }
			else {
				LedHsv.h += HsvStep;
				
				LedRgb = HsvToRgb(LedHsv);
				ext_led_pwm.r = LedRgb.r * RgbToPwm;
				ext_led_pwm.g = LedRgb.g * RgbToPwm;
				ext_led_pwm.b = LedRgb.b * RgbToPwm;
				update_ext_pwm();
				
				HsvStepLinger = 0;
			}
			
			HsvStepDelayCounter = 0;
		}
		else {
			HsvStepDelayCounter++;
		} */
		 
		HAL_Delay(1);
		
		//HAL_GPIO_TogglePin(GPIOE, LED1_Pin);
	}
	
	mqtt_disconnect(&static_client);
  /* USER CODE END 3 */

}

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


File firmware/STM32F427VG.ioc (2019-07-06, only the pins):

Mcu.UserName=STM32F427VGTx
PA1.Signal=ETH_REF_CLK
PA10.GPIO_Label=CAN_STBY
PA10.Signal=GPIO_Output
PA11.Signal=CAN1_RX
PA12.Signal=CAN1_TX
PA13.Signal=SYS_JTMS-SWDIO
PA14.Signal=SYS_JTCK-SWCLK
PA15.Signal=SYS_JTDI
PA2.Signal=ETH_MDIO
PA3.GPIO_Label=PHY_RST
PA3.Signal=GPIO_Output
PA4.Signal=SPI3_NSS
PA6.GPIO_Label=PHY_AD0
PA6.Signal=GPIO_Output
PA7.Signal=ETH_CRS_DV
PA8.Signal=RCC_MCO_1
PB0.GPIO_Label=LED_SYSTEM_B
PB0.Signal=S_TIM3_CH3
PB10.Signal=SPI2_SCK
PB11.Signal=ETH_TX_EN
PB12.Signal=ETH_TXD0
PB13.Signal=ETH_TXD1
PB14.Signal=SPI2_MISO
PB15.Signal=SPI2_MOSI
PB3.Signal=SYS_JTDO-SWO
PB4.Signal=SYS_JTRST
PB5.GPIO_Label=SPI2_CS1
PB5.Signal=GPIO_Output
PB6.GPIO_Label=SPI2_CS0
PB6.Signal=GPIO_Output
PB8.Signal=I2C1_SCL
PB9.Signal=I2C1_SDA
PC1.Signal=ETH_MDC
PC10.Signal=SPI3_SCK
PC11.Signal=SPI3_MISO
PC12.Signal=SPI3_MOSI
PC4.Signal=ETH_RXD0
PC5.Signal=ETH_RXD1
PC8.GPIO_Label=SPI3_CS0
PC8.Signal=GPIO_Output
PC9.GPIO_Label=I2S_CKIN/CS1
PC9.Signal=I2S_CKIN
PD13.GPIO_Label=PWM_R
PD13.Signal=S_TIM4_CH2
PD14.GPIO_Label=PWM_G
PD14.Signal=S_TIM4_CH3
PD15.GPIO_Label=PWM_B
PD15.Signal=S_TIM4_CH4
PD3.Signal=USART2_CTS
PD4.Signal=USART2_RTS
PD5.Signal=USART2_TX
PD6.Signal=USART2_RX
PD8.Signal=USART3_TX
PD9.Signal=USART3_RX
PE0.GPIO_Label=LED0
PE0.Signal=GPIO_Output
PE1.GPIO_Label=LED1
PE1.Signal=GPIO_Output
PE11.GPIO_Label=LED_SYSTEM_R
PE11.Signal=S_TIM1_CH2
PE13.GPIO_Label=PANEL_D1
PE13.Signal=S_TIM1_CH3
PE14.GPIO_Label=PANEL_D2
PE14.Signal=S_TIM1_CH4
PE15.GPIO_Label=LED_CAN
PE15.Signal=GPIO_Output
PE2.GPIO_Label=LED2
PE2.Signal=GPIO_Output
PE3.GPIO_Label=LED3
PE3.Signal=GPIO_Output
PE4.GPIO_Label=LED4
PE4.Signal=GPIO_Output
PE5.GPIO_Label=LED5
PE5.Signal=GPIO_Output
PE6.GPIO_Label=LED6
PE6.Signal=GPIO_Output
PE7.GPIO_Label=LED7
PE7.Signal=GPIO_Output
PE9.GPIO_Label=LED_SYSTEM_G
PE9.Signal=S_TIM1_CH1
PH0/OSC_IN.Signal=RCC_OSC_IN
PH1/OSC_OUT.Signal=RCC_OSC_OUT

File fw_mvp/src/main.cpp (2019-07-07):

/*
	main.cpp - Main file of the LEDNip firmware.
	
	Revision 0
	
	Features:
			- 
			
	Notes:
			- 
			
	2019/06/29, Maya Posch
*/


#include <Wire.h>
#include <WSerial.h>
#include <LwIP.h>
#include <STM32Ethernet.h>
#include <PubSubClient.h>


#define MQTT_HOST "vielseitigkeit.club.entropia.de"
//#define MQTT_HOST "localhost"
#define MQTT_PORT 1883
#define MQTT_USERNAME "user"
#define MQTT_KEY "pass"


// LED channels are connected to the following pins on the MCU:
// PE13: R (Panel 1) 		=> A9
// PE14: G  (Panel 2)		=> A10
// PD13: Red LED string		=> A6
// PD14: Green LED string	=> A7
// PD15: Blue LED string	=> A8
#define RGB_R_PIN PD_13
#define RGB_G_PIN PD_14
#define RGB_B_PIN PD_15
#define PANEL_W PE_13
#define PANEL_Y PE_14


// Weak empty variant initialization function.
// May be redefined by variant files.
void initVariant() __attribute__((weak));
void initVariant() { }


// Ethernet setup
byte mac[]    = {  0xDE, 0xED, 0xBA, 0xFE, 0xFE, 0xED };
// Set the static IP address to use if the DHCP fails to assign
//IPAddress ip(192, 168, 0, 177);
IPAddress ip(10, 214, 227, 243);
EthernetClient STClient;


PubSubClient client(STClient);
long lastMsg = 0;
char msg[8];


// --- CALLBACK ---
// Receive commands here.
void callback(char* topic, byte* payload, unsigned int length) {

#if 0
	Serial.print("Message arrived [");
	Serial.print(topic);
	Serial.print("] ");
	for (unsigned int i = 0; i < length; i++) {
		Serial.print((char)payload[i]);
	}
	Serial.println();
#else
	UNUSED(topic);
#endif
	if (length > 2) {
		// Switch on/off the LED (payload messages can be 'ON' or 'OFF')
		if ((char) payload[0] == 'R') {
		  //digitalWrite(LED_BUILTIN, HIGH); // Turn the LED on
		  analogWrite(RGB_R_PIN, payload[1]);
		}
		else if ((char) payload[0] == 'G') {
		  //digitalWrite(LED_BUILTIN, LOW);  // Turn the LED off
		  analogWrite(RGB_G_PIN, payload[1]);
		}
		else if ((char) payload[0] == 'B') {
		  analogWrite(RGB_B_PIN, payload[1]);
		}
		else if ((char) payload[0] == 'P') {
			if (length > 3) {
				if ((char) payload[1] == 'W') {
					analogWrite(PANEL_W, payload[2]);
				}
				else if ((char) payload[1] == 'Y') {
				  analogWrite(PANEL_Y, payload[2]);
				}
			}
			else {
				Serial.println("Invalid panel command.");
			}
		}
		else {
			Serial.println("Unknown RGB command.");
		}
	}
	else {
		Serial.println("Unknown command.");
	}
}


// --- RECONNECT ---
void reconnect() {
  // Loop until we're reconnected
  while (!client.connected()) {
    Serial.print("Attempting MQTT connection...");
    // Attempt to connect
    // Note - the default maximum packet size is 128 bytes. If the
    // combined length of clientId, username and password exceed this,
    // you will need to increase the value of MQTT_MAX_PACKET_SIZE in
    // PubSubClient.h
    //if (client.connect("STM32Client", MQTT_USERNAME, MQTT_KEY)) {
    if (client.connect("STM32Client")) {
      Serial.println("connected");
      // Once connected, publish an announcement...
      //client.publish(MQTT_USERNAME"/feeds/hello", "Hi, I'm STM32 user!");
      // ... and resubscribe
      client.subscribe("/plants/rgb");
      client.subscribe("/plants/panel");
    } else {
      Serial.print("failed, rc=");
      Serial.print(client.state());
      Serial.println(" try again in 5 seconds");
      // Wait 5 seconds before retrying
      delay(5000);
    }
  }
}


int main() {
	initVariant();
  
	pinMode(LED_BUILTIN, OUTPUT); // Initialize the LED_BUILTIN pin as an output
	Serial.begin(115200);

	client.setServer(MQTT_HOST, MQTT_PORT);
	client.setCallback(callback);

	// Start the Ethernet connection:
	if (Ethernet.begin(mac) == 0) {
		Serial.println("Failed to configure Ethernet using DHCP");
		
		// Try to configure using the IP address instead of DHCP:
		Ethernet.begin(mac, ip);
	}
	// Allow the hardware to sort itself out
	delay(1500);

	// Initialize I2C bus.
	Wire.begin();
	
	
	// --- Setup finished	
	for (;;) {
#if defined(CORE_CALLBACK)
		CoreCallback();
#endif

		if (!client.connected()) {
			reconnect();
		}
		
		client.loop();
	
		if (serialEventRun) {
			serialEventRun();
		}
	}
	
	return 0;
}

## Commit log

2018-10-14 Initial commit. Finish programming/debug interface.
    [mcu.sch, panel_light_control.kicad_pcb, panel_light_control.sch]
2018-10-16 Finished initial schematic review.
    [mcu.sch, panel_light_control.sch]
2018-10-16 Tweak I2S breakout, generate netlist.
    [mcu.sch, panel_light_control.sch]
2018-10-17 Started layouting.
    [panel_light_control.kicad_pcb, panel_light_control.sch]
2018-10-17 Sorted passives on board.
    [mcu.sch, panel_light_control.kicad_pcb, panel_light_control.sch]
2018-10-17 Finished initial layout LED CV, CAN.
    [panel_light_control.kicad_pcb, panel_light_control.sch]
2018-10-17 Finished basic board layout.
    [mcu.sch, panel_light_control.kicad_pcb, panel_light_control.sch]
2018-10-18 Board layout tweaks.
    [panel_light_control.kicad_pcb]
2018-10-18 Tweaking power section layout.
    [panel_light_control.kicad_pcb]
2018-10-18 Finished initial PHY-magjack routing.
    [mcu.sch, panel_light_control.kicad_pcb, panel_light_control.sch]
2018-10-20 adds PHY PU/PD config pin comments
    [mcu.sch]
2018-10-21 schematic clean-up, BOM info partially added
    [mcu.sch, panel_light_control.kicad_pcb, panel_light_control.sch]
2018-10-21 PHY routing done? Current sink routing is back to square one (yay fwd annotations)
    [mcu.sch, panel_light_control.kicad_pcb, panel_light_control.sch]
2018-10-21 further re-arrangement, PCB is now 100x90 mm² \o/. A bit more placement to do, then back to routing :>
    [mcu.sch, panel_light_control.kicad_pcb, panel_light_control.sch]
2018-10-22 Tweaked LED sink layout, fixed 3D model for 1 RJ45 jack.
    [panel_light_control.kicad_pcb]
2018-10-22 Tweaked MOSFET sink layout. Changed LM324 to SOIC.
    [mcu.sch, panel_light_control.kicad_pcb, panel_light_control.sch]
2018-10-22 Add LEDs, tweak MOSFET sink.
    [mcu.sch, panel_light_control.csv, panel_light_control.kicad_pcb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]
2018-10-22 3.3V buck converter now connected to 12V (prep for 48V>12V upgrade regarding IoP applicability)
    [mcu.sch, panel_light_control.kicad_pcb, panel_light_control.sch]
2018-10-22 two sections left to place: 3ch current sink, microcontroller area. Todo: * find proper barrel jacks, spec MPN, Mouser * add status LEDs to the LDD-H outputs * add 7th LED for funsies :> * swap LM324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
    [panel_light_control.kicad_pcb, panel_light_control.sch]
2018-10-23 THT pad restring sizes increase for mechanical stability; generalized LED arrangement for more flexibility (8 bit display, CAN LED, PWM and general purpose RGB) and development-style look and feel; p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
    [mcu.sch, panel_light_control.kicad_pcb, panel_light_control.sch]
2018-10-23 R-78B3.3 footprint fixed (had the E version -> mirrored), next: place remaining current sink circuit parts, route upper half of the PCB, tidy up CAN placement, verify µC pin mapping again, route lowe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
    [panel_light_control.kicad_pcb, panel_light_control.sch]
2018-10-27 RGB current sink placed and routed. All placement should be done now, next: check barrel jack footprint, do power routing, think about input protection for GPIOs, possibly add resistor arrays, route 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
    [panel_light_control.kicad_pcb, panel_light_control.sch]
2018-10-27 silkscreen clean-up
    [panel_light_control.kicad_pcb]
2018-10-27 PS1-> Panel1, PS2-> Panel2, PS12->12V, PS33-> 3.3V.
    [panel_light_control.kicad_pcb, panel_light_control.sch]
2018-10-27 missed silkscreen bits tidied up
    [panel_light_control.kicad_pcb]
2018-10-27 add CAN termination jumper, switch-mode DCDC power routing and current sink routing done. Barrel jacks still need swapping?
    [mcu.sch, panel_light_control.kicad_pcb, panel_light_control.sch]
2018-10-27 change I2S connector footprint back from 11 pin to 10 pin (MCK, SCK, WS... missing something?). More silkscreen clean-up and a bit of routing.
    [panel_light_control.kicad_pcb, panel_light_control.sch]
2018-10-27 minor touch-ups. ToDo: think about barrel jacks, input protection, finish routing (RMII, 3.3V plane and traces, general purpose signals), then review.
    [panel_light_control.kicad_pcb]
2018-10-27 routing almost done. ToDo: fix symbols to include shielding on some connectors. finish routing. Add GND copper pour on bottom side.
    [panel_light_control.kicad_pcb, panel_light_control.sch]
2018-10-27 first pass routing done (0 air wires). ToDo: fix connector shielding.
    [panel_light_control.kicad_pcb]
2018-10-28 all connector shields are now connected to ground. Note HR911105A LED pins are offset by 4.9mm whereas the WE LED pins are at 4.1mm. Can still fit the WE part? but it won't be pretty.
    [mcu.sch, panel_light_control.kicad_pcb, panel_light_control.sch]
2018-10-28 lots of labels!
    [mcu.sch, panel_light_control.kicad_pcb, panel_light_control.sch]
2018-10-28 Removed redundant silkscreen labels.
    [panel_light_control.kicad_pcb]
2018-10-28 Changes to 3.3V polygon shape to remove overlap with 24V, 12V input section. Some improvements and corrections to the silkscreen. 7805 location checked for 78B05 clearance - will work in case 5V >100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
    [panel_light_control.kicad_pcb]
2018-10-28 Added board art.
    [panel_light_control.kicad_pcb]
2018-10-28 added BOM info, minor tweaks to artwork
    [mcu.sch, panel_light_control.kicad_pcb, panel_light_control.sch]
2018-11-01 adds reset button, some xtal guarding. Schematic reviewed in this version, see https://hackmd.io/-iUjavK_Rz-11sfgLlTnuA# - xtal could be swapped for C_L 10 pF version to reduce susceptibility to envi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
    [mcu.sch, panel_light_control.kicad_pcb]
2018-11-04 pinout validated against CubeMX listing (.ioc added), some nets renamed, system RGB LED reconnected. Reconnected I2C lines to include CAN alternate function. Warning: * bottom silkscreen labels might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
    [mcu.sch, panel_light_control.kicad_pcb, panel_light_control.sch]
2018-11-05 swap xtal for 12 MHz type with CL=8pF -> 2MHz PLL in (optimum), larger load capacitors offering higher noise immunity, HSE gain margin should still be ok, silk screen changes due to secondary CAN int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
    [mcu.sch, panel_light_control.kicad_pcb]
2018-11-05 Generated v0.1 Gerbers & Drill file.
    [panel_light_control-B.Cu.gbr, panel_light_control-B.Mask.gbr, panel_light_control-B.Paste.gbr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]
2018-11-05 final touches: add fiducials for PCBA
    [panel_light_control.kicad_pcb, panel_light_control.sch]
2018-11-05 Update Gerbers & Drill files.
    [panel_light_control-B.Cu.gbr, panel_light_control-B.Mask.gbr, panel_light_control-B.Paste.gbr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]
2018-11-06 add project flow diagram for the deployment of 25+ boards. Get draw.io: https://about.draw.io/integrations/#integrations_offline
2018-11-16 BOM DONE
    [mcu.sch, panel_light_control.kicad_pcb, panel_light_control.sch]
2018-11-16 BOM completed, inventory checked and listed in BOM. Adds project diagram.
    [mcu.sch, panel_light_control.sch]
2018-11-25 PLCC-4 RGB LEDs LED9 and LED10 are the wrong parts (common cathode required, part is common anode and different input). Fix: source 0606 LEDs (metric 1616) - RD1616-63RGBC-C2CA or DL-PCB0606RGBC-C2. 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
    [mcu.sch, panel_light_control.sch]
2019-01-01 Created an OpenOCD config file and documentation on it. Added quick protocol of the hardware power-up.
    [LEDNipv01.cfg]
2019-01-01 Add auto-generated firmware. Modify Makefile to add 'flash' target.
    [LEDNipv01.cfg]
2019-01-01 added -event reset-assert to define system reset (replacing srst), including documentation.
    [LEDNipv01.cfg]
2019-01-02 .cfg comments updated
    [LEDNipv01.cfg]
2019-01-02 channel 1 pins are called BDBUSn, names updated. Verified reset things (signal is called nTRST while the function is called trst... which is a bit odd but seems to be valid. The AIRCR write also seem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
    [LEDNipv01.cfg]
2019-01-02 includes answers to the "-event reset-assert" usage question, adds flashing capability to the makefile. In essence, OpenOCD contains all reset functionality needed for an STM32F4 through config and b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
    [LEDNipv01.cfg]
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2019-01-12 Updated project according to .ioc file. Experimentation with RELOAD and PRESCALER to debug TIM4 "clock too slow" issue. APB1: 50MHz, APB2: 100MHz. RELOAD = 10000. PRESCALER = 9: 4 ms period, PRESCALE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
    [STM32F427VG.ioc, main.c, main.h]
2019-01-13 played around with CK_IN prescalers for TIM1 and TIM3..4. APB1 and APB2 timer clocks are both 80 MHz now so TIM1, TIM3 and TIM4 behave consistently. +RCC.48MHZClocksFreq_Value=40000000 +RCC.AHBFreq_V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
    [STM32F427VG.ioc, main.c, main.h]
2019-01-14 sets PHY_RST from push-pull low to open-drain high to release nRST, PHYAD0 is kept low -> 0x00 changed in CubeMX from 1 to 0. Change SPI CS pins from low to high speed GPIO. Current draw is higher an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
    [STM32F427VG.ioc, main.c]
2019-03-10 restored MCO1 = 25 MHz, PHY blinking pattern changed (SPEED on permanently, ACT fast blinking, RMII-RXDn activity) but TXEN only stays high for 6µs max. No SMI activity within 100ms after that.
    [mcu.sch, panel_light_control.sch]
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2019-07-07 [MVP] Tweak MVP code. Ethernet interface not working yet.
    [LEDNipv01.cfg]
2019-07-09 Update for v0.2. Revise schematic and PCB layout. See dev log.
    [mcu.sch, panel_light_control.kicad_pcb, panel_light_control.sch]
2020-04-06 * STM32 pin 99 not connected in layout -> GND * STM32 pin 10 not connected in schematic -> GND * added solder jumpers JP1, JP2 with default bridges to select between new CAN routing options * J2 and 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
    [mcu.sch, panel_light_control.kicad_pcb]

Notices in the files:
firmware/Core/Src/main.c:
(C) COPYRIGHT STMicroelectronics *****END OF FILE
